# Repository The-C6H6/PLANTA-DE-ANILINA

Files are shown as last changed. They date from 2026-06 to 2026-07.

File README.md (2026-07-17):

# Diseño conceptual de una planta industrial de anilina

<div align="center">

**Hidrogenación catalítica de nitrobenceno · 33 000 t/año · Coatzacoalcos, Veracruz**

Proyecto técnico-académico de diseño de planta que integra simulación en Aspen HYSYS, balances de materia y energía, red de integración térmica, P&ID, especificación preliminar de equipos, estimación económica, layout SLP y visualización 3D interactiva.

[**Reporte técnico**](<REPORTE/ANILINA___EQUIPO 6.pdf>) · [**Recorrido 3D**](<3D/VISUALIZACIÓN/GRABACIÓN 3D.mp4>) · [**Modelo interactivo**](<3D/index.standalone.html>) · [**Caso de HYSYS**](<SIMULACIÓN/ANILINA_99.hsc>)

</div>

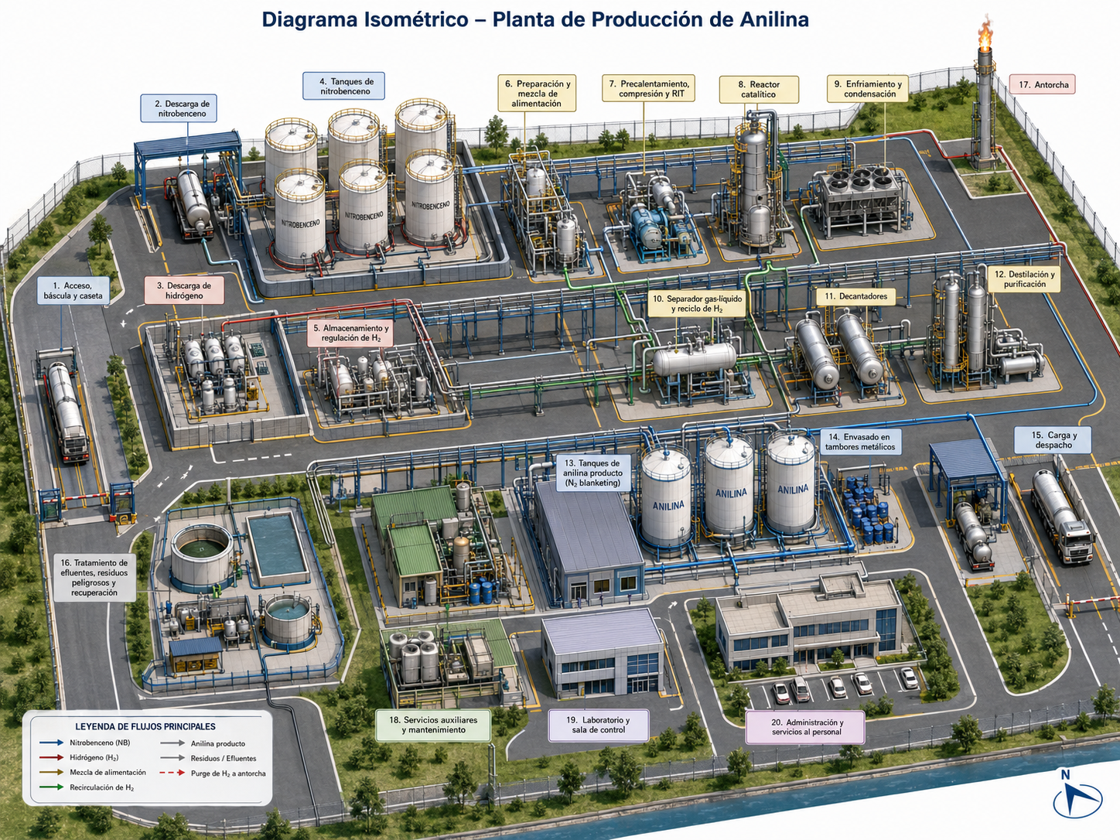
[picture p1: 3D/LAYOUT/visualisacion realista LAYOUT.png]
Vista isométrica de la planta de producción de anilina


> [!IMPORTANT]
> Este es un diseño conceptual con fines académicos. Los datos de proceso, seguridad y costos deben someterse a ingeniería básica y de detalle, HAZOP/LOPA, revisión normativa y validación independiente antes de cualquier uso industrial.

## Contenido

- [Visión general](#visión-general)
- [Fundamento químico](#fundamento-químico)
- [Proceso completo](#proceso-completo)
- [Diagramas de ingeniería y simulación](#diagramas-de-ingeniería-y-simulación)
- [Layout y diseño 3D](#layout-y-diseño-3d)
- [Equipos principales](#equipos-principales)
- [Seguridad y criterios de distribución](#seguridad-y-criterios-de-distribución)
- [Contenido del repositorio](#contenido-del-repositorio)
- [Cómo explorar el proyecto](#cómo-explorar-el-proyecto)
- [Alcance y limitaciones](#alcance-y-limitaciones)

## Visión general

La propuesta desarrolla una planta de operación continua para producir **anilina grado técnico** mediante la hidrogenación catalítica de nitrobenceno. El diseño considera recuperación de materias primas no reaccionadas, integración térmica, separación gas-líquido, decantación, purificación por destilación y manejo final del producto.

La localización conceptual es el entorno industrial del **Complejo Petroquímico Pajaritos, Coatzacoalcos, Veracruz, México**, seleccionado por su infraestructura petroquímica, acceso logístico y cercanía potencial a materias primas y servicios.

| Indicador | Valor de diseño o simulación |
| --- | ---: |
| Producto principal | Anilina grado técnico |
| Capacidad nominal | 33 000 t/año |
| Producción simulada | 32 268.45 t/año |
| Producción horaria | 3.841482 t/h |
| Régimen de operación | 350 días/año; 8 400 h/año |
| Conversión en el reactor | 96 % |
| Pureza molar del producto | 97.7 % |
| Presión aproximada de reacción | 5 bar |
| Temperatura de entrada al reactor | 340 °C |
| Inversión total preliminar | USD 4 070 400 |
| Materias primas | USD 57 161 700/año |
| Servicios auxiliares | USD 1 135 841.82/año |

Los valores económicos corresponden a la estimación académica del proyecto y no representan cotizaciones vigentes de mercado.

## Fundamento químico

La reacción principal es la reducción del grupo nitro del nitrobenceno con hidrógeno:

```text
C6H5NO2 + 3 H2  →  C6H5NH2 + 2 H2O
Nitrobenceno        Anilina       Agua
```

- **Materia prima orgánica:** nitrobenceno.
- **Agente reductor:** hidrógeno.
- **Catalizador considerado:** paladio soportado en alúmina.
- **Producto:** anilina.
- **Subproducto estequiométrico:** agua.
- **Naturaleza del sistema:** reacción exotérmica en fase gaseosa, con control térmico y recuperación de calor.

## Proceso completo

### 1. Alimentación y recuperación de materias primas

El nitrobenceno fresco se combina con el nitrobenceno recuperado en la sección de purificación. En paralelo, el hidrógeno fresco se mezcla con el hidrógeno recirculado desde el separador gas-líquido. Estos reciclos disminuyen pérdidas de reactivos y reducen la demanda de alimentación fresca.

### 2. Precalentamiento e integración térmica

La corriente total de hidrógeno se precalienta en **E-101** hasta aproximadamente 220 °C aprovechando energía del efluente caliente del reactor; después alcanza cerca de 310 °C con servicio de calentamiento. El nitrobenceno sigue un acondicionamiento equivalente mediante recuperación de calor y calentamiento final hasta aproximadamente 310 °C.

### 3. Mezcla, compresión y reacción

Las alimentaciones calientes se mezclan y se comprimen hasta cerca de 5 bar. Antes de ingresar al reactor catalítico **CRV-100**, la mezcla alcanza aproximadamente 340 °C. La conversión de nitrobenceno establecida en la simulación es de 96 %. Debido al carácter exotérmico de la reacción, el reactor requiere control de temperatura y una estrategia de remoción de calor.

### 4. Enfriamiento y recuperación de hidrógeno

El efluente del reactor, compuesto por anilina, agua, hidrógeno y nitrobenceno no reaccionados, entrega parte de su energía a las corrientes frías del proceso. Posteriormente se enfría hasta unos 30 °C y entra al separador **V-101**. La fase gaseosa rica en H₂ se divide entre una purga de seguridad hacia antorcha y una corriente de recirculación.

### 5. Decantación de la fase líquida

La fase líquida pasa al decantador **V-100**, donde se separa una fase acuosa de una fase orgánica rica en anilina y nitrobenceno. La separación líquido-líquido reduce la carga de agua que llegará a la destilación.

### 6. Primera etapa de destilación

La fase orgánica se acondiciona a unos 110 °C antes de entrar a **T-101**. Esta columna retira agua residual, compuestos ligeros e impurezas. Una segunda decantación en **V-102** recupera la fracción orgánica presente en la corriente superior.

### 7. Purificación final y reciclo de nitrobenceno

Las corrientes orgánicas recuperadas se combinan en **MIX-102** y alimentan la segunda columna, **T-100**. La columna opera al vacío, aproximadamente a 0.05 atm en el modelo, para efectuar la separación final anilina-nitrobenceno. La anilina sale como producto con una pureza aproximada de 97.7 % mol; el nitrobenceno de fondos regresa al inicio del proceso.

### 8. Almacenamiento, envasado y despacho

El producto purificado se dirige a tanques con blanketing de nitrógeno, seguido de envasado en tambores metálicos o carga a transporte. El layout incorpora laboratorio, sala de control, servicios auxiliares, mantenimiento y tratamiento de efluentes.

## Diagramas de ingeniería y simulación

### Diagrama de bloques

La vista de bloques resume la trayectoria principal y muestra los dos lazos de recuperación: **A** para nitrobenceno y **B** para hidrógeno.

Diagrama de bloques del proceso de anilina

[Abrir el diagrama de bloques original en PDF](<DIAGRAMAS/Bloques Anilina.pdf>)

### Diagrama de flujo sin integración térmica

Esta representación identifica los equipos principales y permite seguir el proceso base antes de incorporar los intercambios de energía entre corrientes.

Diagrama de flujo del proceso sin integración térmica

[Abrir el diagrama de flujo original en PDF](<DIAGRAMAS/Diagrama de flujo sin integración termica.pdf>)

### Red de Integración Térmica (RIT)

La RIT aprovecha el efluente caliente del reactor para precalentar corrientes de alimentación. En particular, **E-101** recupera calor para el hidrógeno y la red asociada a **E-106** reduce la carga térmica del acondicionamiento de nitrobenceno/mezcla reactiva. Los calentadores y enfriadores de servicio completan los niveles de temperatura requeridos.

Red de integración térmica de la planta de anilina

[Abrir el archivo editable de la RIT](DIAGRAMAS/RIT.eddx)

### Simulación en Aspen HYSYS

El flowsheet integra alimentaciones frescas, reciclos, reactor de conversión, separadores, decantadores, columnas y corrientes de energía. Los archivos de simulación permiten consultar propiedades, composiciones y resultados del caso.

Flowsheet de simulación en Aspen HYSYS

[Abrir el caso de Aspen HYSYS](<SIMULACIÓN/ANILINA_99.hsc>) · [Consultar tablas de corrientes](TUBERIAS)

### Diagramas de tuberías e instrumentación (P&ID)

El repositorio incluye entregables en PDF y DWG para los principales nodos del proceso:

| Subsistema | Documentos destacados |
| --- | --- |
| Almacenamiento y protección | [Tanque de nitrobenceno](<PID/PDF/TANQUE DE NITROBENCENO.pdf>) · [Tanque de hidrógeno](<PID/PDF/TANQUE DE HIDROGENO.pdf>) · [Blanketing](PID/PDF/BLANKETING.pdf) |
| Alimentación y reacción | [Compresor](PID/PDF/COMPRESOR.pdf) · [Mezclador MIX-102](<PID/PDF/MIXER 102.pdf>) · [Reactor enchaquetado](<PID/PDF/REACTOR ENCHAQUETADO.pdf>) |
| Enfriamiento y separación | [Separador V-101](PID/PDF/SEPARADOR001.pdf) · [Decantador V-100](<PID/PDF/DECANTADOR V100.pdf>) · [Decantador V-102](<PID/PDF/DECANTADOR V102.pdf>) |
| Purificación | [Columna T-100](<PID/PDF/Columna de destilacion T_100.pdf>) · [Columna T-101](<PID/PDF/Columna de destilacion T_101.pdf>) |
| Recuperación térmica | [Intercambiador de H₂](<PID/PDF/INTERCAMBIADOR DE H2.pdf>) · [Intercambiador de mezcla](<PID/PDF/INTERCAMBIADOR DE MEZCLA.pdf>) · [E-105](<PID/PDF/INTERCAMBIADOR DESPUES NITROBENCENO.pdf>) |
| Seguridad | [Antorcha](PID/PDF/TORCH.pdf) |

[Explorar todos los P&ID en PDF](PID/PDF) · [Explorar los archivos DWG](PID/DWG)

## Layout y diseño 3D

### Distribución conceptual por bloques

El layout se desarrolló con un enfoque **SLP (Systematic Layout Planning)**. La secuencia física sigue el flujo recepción → almacenamiento → reacción → separación → purificación → producto → despacho, mientras las áreas de mayor riesgo se mantienen segregadas.

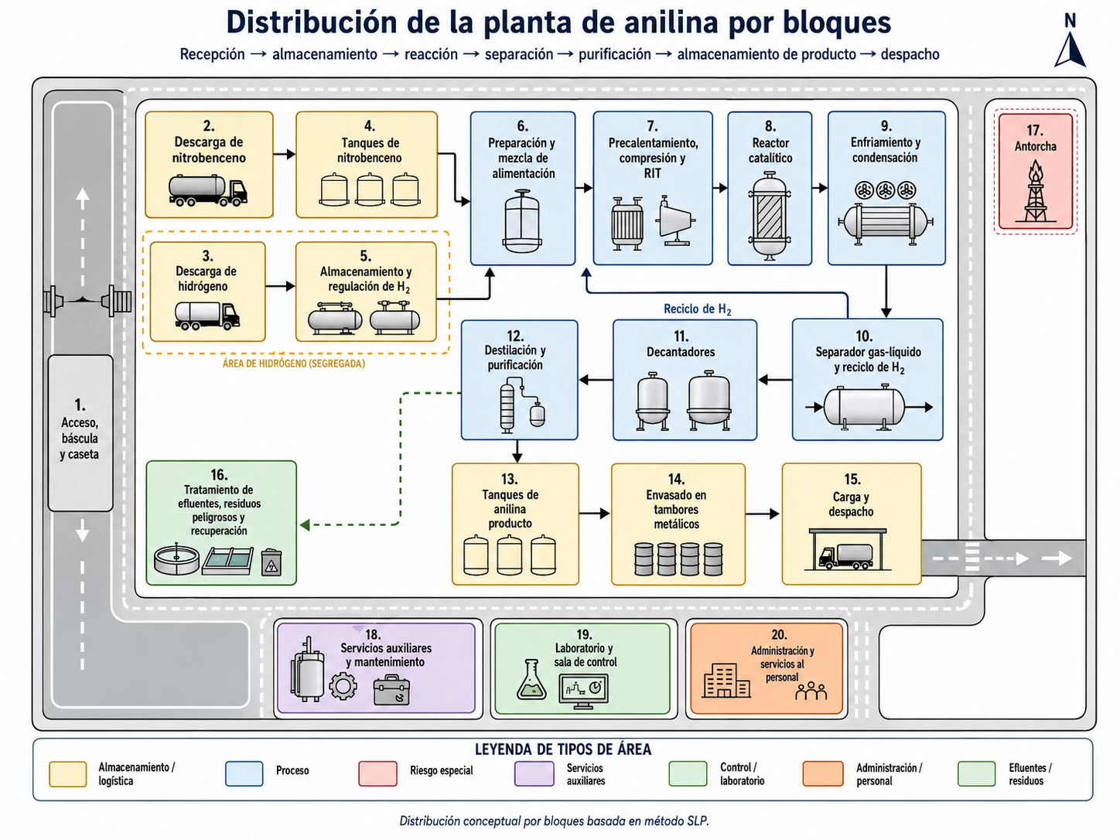
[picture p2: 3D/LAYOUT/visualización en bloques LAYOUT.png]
Distribución de la planta de anilina por bloques


| Zonas | Función dentro del layout |
| --- | --- |
| 1-5 | Acceso, báscula, descarga y almacenamiento de nitrobenceno e hidrógeno |
| 6-12 | Preparación de alimentación, compresión, reacción, enfriamiento, separación y purificación |
| 13-15 | Almacenamiento de anilina, envasado, carga y despacho |
| 16-17 | Tratamiento de efluentes y antorcha |
| 18-20 | Servicios, mantenimiento, laboratorio, sala de control y administración |

### Vista isométrica realista

La representación isométrica convierte los bloques funcionales en una propuesta espacial con vialidades, racks de tuberías, diques de contención, áreas de carga, servicios, edificios y equipos principales.

Layout isométrico realista de la planta

### Recorrido en video

La imagen siguiente funciona como portada del recorrido. Selecciónala para abrir el archivo MP4 del modelo 3D.

Reproducir recorrido 3D de la planta de anilina

▶ **[Reproducir o descargar la grabación 3D](<3D/VISUALIZACIÓN/GRABACIÓN 3D.mp4>)**

### Modelo Three.js interactivo

El archivo autónomo [3D/index.standalone.html](<3D/index.standalone.html>) contiene el modelo y la biblioteca necesaria en una sola página. Permite:

- orbitar, acercar y alejar la cámara;
- enfocar materias primas, reacción, separación, producto y servicios;
- activar o desactivar etiquetas y tuberías;
- usar giro automático;
- recorrer la planta en modo juego con `WASD`, ratón y `Shift`.

Para ejecutarlo, descarga el repositorio y abre el archivo HTML en un navegador moderno; no requiere instalación ni servidor local.

## Equipos principales

| Sección | Equipos o etiquetas representativas | Función |
| --- | --- | --- |
| Alimentación | T-01/T-02, MIX-103, MIX-101 | Almacenamiento, combinación de corrientes frescas y reciclos |
| Acondicionamiento | E-100, H-100, E-101, E-106 | Precalentamiento con servicios e integración térmica |
| Compresión | CO-100 | Elevar la presión de la mezcla reactiva |
| Reacción | CRV-100 | Conversión catalítica de nitrobenceno a anilina |
| Enfriamiento | E-101, E-103 | Recuperación de calor y condensación del efluente |
| Separación primaria | V-101 | Separación de H₂ y fase líquida; reciclo y purga |
| Decantación | V-100, V-102 | Separación de agua y recuperación de fase orgánica |
| Purificación | T-101, T-100, MIX-102 | Remoción de ligeros/agua y separación final al vacío |
| Seguridad y almacenamiento | Antorcha, tanques de producto, blanketing de N₂ | Manejo de purgas y conservación segura del producto |

Las hojas preliminares disponibles incluyen el análisis hidráulico de **T-101**, la especificación de la columna y archivos de diseño del intercambiador **E-105**. Véase [ESPECIFICACIÓNES DE EQUIPOS](<ESPECIFICACIÓNES DE EQUIPOS>).

## Seguridad y criterios de distribución

- **Hidrógeno:** almacenamiento segregado, control de fuentes de ignición, venteos y purgas dirigidos a un sistema seguro.
- **Nitrobenceno y anilina:** manejo en sistemas cerrados, contención secundaria, ventilación, detección de fugas y tratamiento de derrames/efluentes.
- **Reacción exotérmica:** control independiente de temperatura y presión, alarmas, interbloqueos, alivio y aislamiento de emergencia.
- **Antorcha:** ubicación periférica para recibir la purga de hidrógeno y otras descargas previstas por el diseño.
- **Tránsito y emergencia:** vialidad perimetral, accesos diferenciados, zonas de carga separadas y espacio para atención de emergencias.
- **Operación:** sala de control y laboratorio fuera del núcleo de proceso, con servicios y mantenimiento próximos pero físicamente diferenciados.

Estas medidas son criterios conceptuales; la selección final de distancias, protecciones, instrumentación y sistemas contra incendio requiere estudios formales de riesgo y cumplimiento de la normativa aplicable.

## Contenido del repositorio

| Recurso | Ubicación | Contenido |
| --- | --- | --- |
| Reporte completo | [REPORTE](REPORTE) | Documento técnico de 126 páginas en PDF |
| Documento editable | [WORD](WORD) | Versión DOCX del reporte |
| Simulación | [SIMULACIÓN](<SIMULACIÓN>) | Caso y respaldo de Aspen HYSYS |
| Diagramas de proceso | [DIAGRAMAS](DIAGRAMAS) | Bloques, flujo sin integración térmica y RIT |
| P&ID | [PID/PDF](PID/PDF) y [PID/DWG](PID/DWG) | Diagramas por equipo en formatos de consulta y edición |
| Diseño 3D | [3D](3D) | Modelo Three.js, layouts, memoria y grabación MP4 |
| Equipos | [ESPECIFICACIÓNES DE EQUIPOS](<ESPECIFICACIÓNES DE EQUIPOS>) | Hojas y análisis de equipos seleccionados |
| Tuberías y corrientes | [TUBERIAS](TUBERIAS) | Propiedades, composiciones, energía, diámetros y resumen |
| Costos de equipos | [COSTOS DE EQUIPOS](<COSTOS DE EQUIPOS>) | Estimación en Excel por equipo |
| Costos totales | [COSTOS TOTALES](<COSTOS TOTALES>) | Inversión y costo anual del proceso |
| Servicios auxiliares | [SERVICIOS DE LA PLANTA](<SERVICIOS DE LA PLANTA>) | Consumos y costos de servicios |

## Cómo explorar el proyecto

1. Comienza con el [reporte técnico completo](<REPORTE/ANILINA___EQUIPO 6.pdf>) para revisar bases, balances, localización, costos y referencias.
2. Revisa el [diagrama de bloques](<DIAGRAMAS/Bloques Anilina.pdf>) y la [RIT](DIAGRAMAS/RIT.jpg) para entender la lógica del proceso.
3. Abre [3D/index.standalone.html](<3D/index.standalone.html>) localmente para recorrer la distribución de planta.
4. Reproduce la [grabación 3D](<3D/VISUALIZACIÓN/GRABACIÓN 3D.mp4>) si deseas una visita guiada sin interactuar con el modelo.
5. Usa [SIMULACIÓN/ANILINA_99.hsc](<SIMULACIÓN/ANILINA_99.hsc>) en una instalación compatible de Aspen HYSYS para consultar o recalcular el caso.
6. Profundiza en los [P&ID](PID/PDF), las [tablas de tuberías](TUBERIAS) y los [libros de costos](<COSTOS TOTALES>).

## Alcance y limitaciones

El proyecto cubre selección de ruta, localización conceptual, descripción del proceso, simulación, diagramas, equipos principales, tuberías, servicios, costos, layout y representación 3D. No sustituye:

- ingeniería básica o de detalle certificada;
- validación experimental de cinética y catalizador;
- diseño mecánico completo y cálculo estructural;
- análisis dinámico, SIL, HAZOP, LOPA o QRA;
- permisos ambientales, uso de suelo o cumplimiento regulatorio;
- cotizaciones comerciales y evaluación financiera con precios actualizados.

## Contexto académico

| Campo | Información |
| --- | --- |
| Institución | Instituto Politécnico Nacional |
| Escuela | Escuela Superior de Ingeniería Química e Industrias Extractivas |
| Materia | Diseño de Plantas Industriales |
| Grupo | 5IM93 |
| Profesor | Gasca Reyes Luis Germán |
| Fecha de entrega | 27 de junio de 2026 |

### Integrantes

- Vázquez Pérez Diego
- Hernández González Mónica
- Esquivel Arriaga Isaac

---

Si este repositorio te resulta útil, consulta el reporte para conocer las bases de cálculo, supuestos y referencias que respaldan cada sección del diseño.

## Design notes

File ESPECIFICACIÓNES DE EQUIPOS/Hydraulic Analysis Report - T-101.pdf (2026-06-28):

# Hydraulic Analysis Report - T-101 : Internals-1@Main Tower@COL1

## Generated by Aspen HYSYS V14

## Simulation case: C:\Users\C6H6_\Downloads\ANILINA_99.hsc

23/06/2026

# Contents

1. Column Internals Summary--------------------------------------------------------------------------------------------------------------- 3
2. Feed/Draw Summary----------------------------------------------------------------------------------------------------------------------- 4
3. CS-1---------------------------------------------------------------------------------------------------------------------------------------------5
3.1. Tray Geometry----------------------------------------------------------------------------------------------------------------------------- 5
3.2. Design Parameters------------------------------------------------------------------------------------------------------------------------7

## Hydraulic Analysis Report - T-101 : Internals-1@Main Tower@COL1

User Name: | ESIQIE | Job Code:
Project: | T-101 | Description: | TORRE DE DESTILACION T-101
1. Column Internals Summary
| | Summary
Property | Value | Units
Number of Trayed/Packed stages | 6
Total height | 3.658 | m
Total head loss (Hot liquid height) | 437.5 | mm
Total pressure drop | 40.89 | mbar
Number of sections | 1
Number of diameters | 1
Total residence time | 8.488 | seconds

Sections
Section | Start | End | Diameter (m) | Section Height (m) | Internals Type | Tray or Packing Type | Section Pressure Drop (mbar) | % Approach to Flood | Limiting Stage
CS-1 | 1_Main Tower | 6_Main Tower | 0.5044 | 3.658 | Trayed | Sieve | 40.89 | 80.0003 | 6_Mai n Tower
Page 3 of 7 | 23/06/2026

User Name: | ESIQIE | Job Code:
Project: | T-101 | Description: | TORRE DE DESTILACION T-101
2. Feed/Draw Summary
| | Feed/Draw Summary
Stage Number | Stream | Feed/Draw
1_Main Tower | Reflux | Feed
| ORG-110 | Feed
| To Condenser | Draw
6_Main Tower | Boilup | Feed
| To Reboiler | Draw
Page 4 of 7 | 23/06/2026

User Name: | ESIQIE | Job Code:
Project: | T-101 | Description: | TORRE DE DESTILACION T-101
3. CS-1
3.1. Tray Geometry
| | Section
Property | Value | Units
Tray type | SIEVE
Diameter | 0.5044 | m
Tray spacing | 0.6096 | m
Number of passes | 1
Hole diameter | 0.0127 | m
Hole area / Active area | 0.1
Number of Holes | 126
Deck gauge thickness | 10 GAUGE
Deck gauge thickness value | 3.404 | mm
Cross-sectional area | 0.1998 | m2
Active area | 0.1598 | m2
Net area | 0.1798 | m2

Downcomer geometry

Property | Side | Units
Downcomer clearance | 0.0381 | m
Downcomer width top | 0.07892 | m
Downcomer width bottom | 0.07892 | m
Downcomer area top | 0.01998 | m2
Downcomer area bottom | 0.01998 | m2

Weir geometry

Property | Side | Units
Weir height | 0.0508 | m
Page 5 of 7 | 23/06/2026

User Name: | ESIQIE | Job Code:
Project: | T-101 | Description: | TORRE DE DESTILACION T-101
Property | Side | Units
Weir length | 0.3665 | m

Panels

Property | A | Units
Flow path length | 0.3465 | m
Bubbling area | 0.1598 | m2
Page 6 of 7 | 23/06/2026

User Name: | ESIQIE | Job Code:
Project: | T-101 | Description: | TORRE DE DESTILACION T-101
3.2. Design Parameters
Design Parameters
Property | Value | Units
% Jet flood and downcomer choke flood for design | 80
Minimum downcomer area / Total tray area | 0.1

Downcomer design basis

Maximum acceptable pressure drop | 2.5 | kPa
Maximum % jet flood | 100
Maximum % downcomer backup | 100
Maximum % liquid entrainment | 10
Minimum weir loading | 4.471 | m3/h-m
Maximum weir loading | 117.4 | m3/h-m
Warning status (% to limit) | 10
System foaming factor | 1
Aeration factor multiplier | 1
Over design factor | 1
Overall section efficiency | 1
Weep method | Hsieh
Jet flood method | Glitsch6
Maximum downcomer loading method | Glitsch
Dry pressure drop multiplier | 1
Page 7 of 7 | 23/06/2026

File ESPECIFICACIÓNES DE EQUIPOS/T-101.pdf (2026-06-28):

Company Name Not Available Bedford, MA
USA
Case Name: | ANILINA_99.hsc
Unit Set: | SI10a1
Date/Time: | Wed Jun 24 18:48:37 2026

# Distillation: T-101 @Main

### CONNECTIONS

11 | Inlet Stream
12 | Stream Name | Stage | From Unit Operation
13 | R-T101 | Reboiler
14 | ORG-110 | 1__Main Tower | Heater E-104
15 | Outlet Stream
16 | Stream Name | Stage | To Unit Operation
17 | C-T101 | Condenser
18 | H2O | Condenser | 3 Phase Separator V-102
19 | ORG-SEP | Reboiler | Cooler E-105
20 | H2 | Condenser
21 | MONITOR
23 | Specifications Summary
24 | | Specified Value | Current Value | Wt. Error
25 | Reflux Ratio | 2.000 * | 2.000 | -2.839e-008
26 | Distillate Rate | --- | 14.36 kgmole/h | ---
27 | Reflux Rate | 30.16 kgmole/h * | 28.85 kgmole/h | -4.341e-002
28 | Btms Prod Rate | --- | 41.62 kgmole/h | ---
29 | Vent Rate | 7.000e-002 kgmole/h * | 7.000e-002 kgmole/h | 3.773e-006
30 | REC H2O | 0.9900 * | 0.9900 | 9.044e-008
31 | | Wt. Tol. | Abs. Tol. | Active | Estimate | Used
32 | Reflux Ratio | 1.000e-002 | 1.000e-002 | On | On | On
33 | Distillate Rate | 1.000e-002 | 1.000 kgmole/h | Off | Off | Off
34 | Reflux Rate | 1.000e-002 | 1.000 kgmole/h | Off | On | Off
35 | Btms Prod Rate | 1.000e-002 | 1.000 kgmole/h | Off | On | Off
36 | Vent Rate | 1.000e-002 | 1.000 kgmole/h | On | On | On
37 | REC H2O | 1.000e-002 | 1.000e-003 | On | On | On
38 | SPECS
40 | Column Specification Parameters
41 | Reflux Ratio
43 | Fix/Rang: Fixed | Prim/Alter: Primary | Lower Bnd: --- | Upper Bnd: ---
44 | Stage: Condenser | Flow Basis: Molar | Liquid Spec: ---
45 | Distillate Rate
47 | Fix/Rang: Fixed | Prim/Alter: Primary | Lower Bnd: --- | Upper Bnd: ---
48 | Stream: H2O | Flow Basis: Molar
49 | Reflux Rate
51 | Fix/Rang: Fixed | Prim/Alter: Primary | Lower Bnd: --- | Upper Bnd: ---
52 | Stage: Condenser | Flow Basis: Molar | Liquid Spec: ---
53 | Btms Prod Rate
55 | Fix/Rang: Fixed | Prim/Alter: Primary | Lower Bnd: --- | Upper Bnd: ---
56 | Stream: ORG-SEP | Flow Basis: Molar
57 | Vent Rate
59 | Fix/Rang: Fixed | Prim/Alter: Primary | Lower Bnd: --- | Upper Bnd: ---
60 | Stream: H2 | Flow Basis: Molar
61
Aspen Technology Inc. | Aspen HYSYS Version 14 | Page 1 of 11

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
Licensed to: Company Name Not Available | * Specified by user.

| Bedford, MA USA
6 | Distillation: T-101 @Main (continued)
Unit Set: | SI10a1
Date/Time: | Wed Jun 24 18:48:37 2026
9 | Column Specification Parameters
10 | REC H2O
12 | Fix/Rang: Fixed | Prim/Alter: Primary | Lower Bnd: --- | Upper Bnd: ---
13 | Draw: H2O | Flow Basis: Molar
14 | Components: | H2O
15 | SUBCOOLING
17 | | Condenser
18 | Degrees of Subcooling | ---
19 | Subcool to | ---
20 | User Variables

### ACTIVE INTERNAL OPTION: Internals-1@Main Tower@COL1

24 | Name | Start Stage | End Stage | Mode | Internals | Tray / Packing Type
25 | CS-1 | 1__Main Tower | 6__Main Tower | Interactive Sizing | Trayed | Sieve
26 | Number of Passes | Packing Vendor | Packing Material | Packing Dimension | Tray Spacing / Section Packed Height (m) | Diameter (m)
28 | 1 | --- | --- | --- | 0.6096 | 0.5044
29 | SETUP
31 | Section Name | CS-1
32 | Section Start | 1__Main Tower
33 | Section End | 6__Main Tower
34 | Internals | Trayed
35 | Internals Type | Sieve
36 | Diameter (m) | 0.5044
37 | Tray Spacing / Section Packed Height (m) | 0.6096
38 | Number Of Passes | 1
39 | Maximum Acceptable Pressure Drop (kPa) | 2.500
40 | Maximum Percent Downcomer Backup | 100.00 %
41 | Maximum Percent Jet Flood | 100.00 %
42 | Percent Jet Flood For Design | 80.00 %
43 | Maximum Percent Liquid Entrainment | 10.00 %
44 | Minimum Weir Loading (m3/h-m) | 4.471
45 | Maximum Weir Loading (m3/h-m) | 117.4
46 | Minimum Downcomer Area / Total Tray Area | 0.1000
47 | Override Downcomer Froth Density | No
48 | Froth Density | ---
49 | Weep Method | Hsieh
50 | Default Jet Flood Calculation Method | GLITSCH6
51 | Maximum Downcomer Loading Method | Glitsch
52 | % Approach to Maximum Capacity | ---
53 | Design Capacity Factor | ---
54 | Capacity Factor at Flooding | ---
55 | System Foaming Factor | 1.000
56 | Aeration Factor Multipler | 1.000
57 | Minimum Liquid Flow Rate | ---
58 | Pressure Drop at Flood per Unit Packed Height | ---
59 | Allowable Pressure Drop per Unit Packed Height | ---
60 | Minimum Pressure Drop per Unit Packed Height | ---
| Number of Curves | ---
| Warning Status (% to Limit) | 10.00 % *
| Aspen Technology Inc. Aspen HYSYS Version 14 Page 2 of 11

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
| Bedford, MA USA
6 | Distillation: T-101 @Main (continued)
Unit Set: | SI10a1
Date/Time: | Wed Jun 24 18:48:37 2026

### ACTIVE INTERNAL OPTION: Internals-1@Main Tower@COL1

### SETUP

13 | Pressure Drop Calculation Method | ---
14 | Mode | Interactive Sizing
15 | Status | Needs Calculating
16 | GEOMETRY DETAILS
18 | Common Geometry | CS-1
19 | Section Start | 1__Main Tower
20 | Section End | 6__Main Tower
21 | Internals | Sieve
22 | Section Diameter (m) | 0.5044
23 | Foaming Factor | 1.000
24 | Over-Design Factor | 1.000
25 | Common Tray Geometry | CS-1
26 | Number of Passes | 1
27 | Tray Spacing (m) | 0.6096
28 | Picket Fence Weirs | No
29 | Swept Back Weirs | No
30 | Active Area Under Downcomer | No
31 | Deck Thickness | 10 Gauge
32 | Deck Thickness Value (mm) | 3.404
33 | Balance Downcomers Based On
34 | Weir Modifications | None
35 | Net Area (m2) | 0.1798
36 | Cross-Sectional Area (m2) | 0.1998
37 | Active Area (m2) | 0.1598
38 | Downcomer Geometry | CS-1
39 | Side | Weir Height (mm) | 50.80 *
40 | | Weir Length (m) | ---
41 | | Downcomer Clearance (mm) | 38.10
42 | | Downcomer Width - Top (mm) | 78.92
43 | | Downcomer Width - Bottom (mm) | 78.92
44 | | Downcomer Loading Top (m3/h-m2) | 238.3 *
45 | | Weir Loading (m3/h-m) | 19.76
46 | | Downcomer Area - Top (m2) | 1.998e-002
47 | | Downcomer Area - Bottom (m2) | 1.998e-002
48 | | Picketing Fraction | ---
49 | Center | Weir Height (mm) | ---
50 | | Weir Length (m) | ---
51 | | Downcomer Clearance (mm) | ---
52 | | Downcomer Width - Top (mm) | ---
53 | | Downcomer Width - Bottom (mm) | ---
54 | | Downcomer Loading Top (m3/h-m2) | ---
55 | | Weir Loading (m3/h-m) | ---
56 | | Downcomer Area - Top (m2) | ---
57 | | Downcomer Area - Bottom (m2) | ---
58 | | Picketing Fraction | ---
59 | Off Center | Weir Height (mm) | ---
60 | | Inside Weir Length (m) | ---
| | Outside Weir Length (m) | ---
| | Downcomer Clearance (mm) | ---
| Aspen Technology Inc. Aspen HYSYS Version 14 Page 3 of 11

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
| Bedford, MA USA
6 | Distillation: T-101 @Main (continued)
Unit Set: | SI10a1
Date/Time: | Wed Jun 24 18:48:37 2026

### ACTIVE INTERNAL OPTION: Internals-1@Main Tower@COL1

### GEOMETRY DETAILS

13 | Off Center | Downcomer Width - Top (mm) | ---
14 | | Downcomer Width - Bottom (mm) | ---
15 | | Downcomer Loading Top (m3/h-m2) | ---
16 | | Maximum Outside Weir Loading(m3/h-m) | ---
17 | | Maximum Inside Weir Loading (m3/h-m) | ---
18 | | Downcomer Area - Top (m2) | ---
19 | | Downcomer Area - Bottom (m2) | ---
20 | | Inside Picketing Fraction | ---
21 | | Outside Picketing Fraction | ---
22 | | Off-Center Downcomer Location (m) | ---
23 | Swept Back Weir Geometry | | CS-1
24 | Compatibility | | KG Tower
25 | A | | ---
26 | B/Parallel Chord Segment | | ---
27 | S/Swept-Back Weir | | ---
28 | Swept-Back Weir Chord | | ---
29 | Angled Chord Segment | | ---
30 | Tray With Maximum Weir Loading | | 6
31 | Maximum Weir Loading (m3/h-m) | | 19.76 *
32 | Maximum Allowable Weir Loading in Section(m3/h-m) | | 117.4 *
33 | Actual Side Weir Length (m) | | 0.3665
34 | Effective Side Weir Length (m) | | 0.3665
35 | Lost Area (%) | | 0.00
36 | Sieve Geometry | | CS-1
37 | Hole Diameter (mm) | | 12.70
38 | Number of Holes | | 126
39 | Hole Area to Active Area | | 0.1000
40 | Lattice Geometry | | CS-1
41 | Number Of Downcomers | | ---
42 | Downcomer End Gap (mm) | | ---
43 | Downcomer Width (mm) | | ---
44 | Downcomer Height (m) | | ---
45 | Downcomer Spacing (m) | | ---
46 | Liq Exit Area / Bottom Downcomer Area | | ---
47 | Weir Height (mm) | | ---
48 | Bubble Cap Geometry | | CS-1
49 | Cap Diameter | | ---
50 | Skirt Height | | ---
51 | Number of Caps | | ---
52 | Number of Caps Per Active Area | | ---
53 | Valve Geometry | | CS-1
54 | Tray Type | | ---
55 | Valve Type | | ---
56 | Valve Material | | ---
57 | Leg Length | | ---
58 | Valve Thickness | | ---
59 | Number of Valves | | ---
60 | Number of Valves per Active Area | | ---
Aspen Technology Inc. | Aspen HYSYS Version 14 | Page 4 of 11

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

### ACTIVE INTERNAL OPTION: Internals-1@Main Tower@COL1

### RESULTS SUMMARY

13 | Section Name | CS-1
14 | Section Start | 1__Main Tower
15 | Section End | 6__Main Tower
16 | Internals | Trayed
17 | Diameter (m) | 0.5044
18 | Number of Passes | 1
19 | Tray Spacing / Section Packed Height (m) | 0.6096
20 | Total Height (m) | 3.658
21 | Total Pressure Drop (mbar) | 40.89
22 | Total Pressure Drop (Head Loss) (mm) | 437.5
23 | Trays With Weeping | None
24 | Maximum Percent Jet Flood (%) | 80.00 *
25 | Tray With Maximum Jet Flood | 6__Main Tower
26 | Maximum Percent Downcomer Backup (%) | 37.38 *
27 | Tray With Maximum Downcomer Backup | 6__Main Tower
28 | Maximum Downcomer Loading (m3/h-m2) | 362.4 *
29 | Tray With Maximum Downcomer Loading | 6__Main Tower
30 | Maximum Downcomer Loading Location | Side
31 | Maximum Weir Loading (m3/h-m) | 19.76 *
32 | Tray With Maximum Weir Loading | 6__Main Tower
33 | Maximum Weir Loading Location | Side
34 | Maximum Aerated Height Over Weir (mm) | 104.1 *
35 | Tray With Maximum Aerated Height Over Weir | 6__Main Tower
36 | Maximum % Approach To System Limit (%) | 50.90 *
37 | Tray With Maximum % Approach To System Limit | 6__Main Tower
38 | Maximum Cs Based On Bubbling Area (m/s) | 0.1051 *
39 | Tray With Maximum Cs Based On Bubbling Area | 6__Main Tower
40 | Maximum % Capacity (Constant L/V) | 80.00
41 | Maximum Capacity Factor (m/s) | ---
42 | Section Pressure Drop (mbar) | 40.89
43 | Average Pressure Drop Per Height (mbar/m) | ---
44 | Average Pressure Drop Per Height (Frictional) (mbar/m) | ---
45 | Maximum Stage Liquid Holdup (m3) | ---
46 | Maximum Liquid Superficial Velocity (m3/h-m2) | ---
47 | Surface Area (m2/m3) | ---
48 | Void Fraction | ---
49 | 1st Stichlmair Constant | ---
50 | 2nd Stichlmair Constant | ---
51 | 3rd Stichlmair Constant | ---
52 | STAGE BY STAGE RESULTS: CS-1
54 | State Conditions
55 | Stages | Liquid Temperature (C) | Vapor Temperature (C) | Liquid Mass Flow (kg/h) | Vapor Mass Flow (kg/h) | Liquid Volume Flow (m3/s) | Vapor Volume Flow (m3/s)
57 | 1__Main Tower | 94.65 | 99.09 | 4592 | 860.9 | 1.323e-003 | 0.3389
58 | 2__Main Tower | 94.66 | 94.66 | 4592 | 673.9 | 1.323e-003 | 0.2702
59 | 3__Main Tower | 94.66 | 94.69 | 4592 | 674.1 | 1.323e-003 | 0.2702
60 | 4__Main Tower | 94.69 | 96.62 | 4601 | 683.0 | 1.325e-003 | 0.2711
| 5__Main Tower | 96.62 | 134.2 | 4961 | 1042 | 1.433e-003 | 0.2810
| 6__Main Tower | 134.2 | 179.3 | 6718 | 2800 | 2.011e-003 | 0.3360
| Aspen Technology Inc. Aspen HYSYS Version 14 Page 5 of 11

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

### ACTIVE INTERNAL OPTION: Internals-1@Main Tower@COL1

### STAGE BY STAGE RESULTS: CS-1

13 | Physical Conditions
14 | Stages | Liquid Molecular Weight | Vapor Molecular Weight | Liquid Mass Density (kg/m3) | Vapor Mass Density (kg/m3) | Liquid Viscosity (cP) | Vapor Viscosity (cP) | Surface Tension (dyne/cm)
16 | 1__Main Tower | 62.19 | 21.55 | 964.4 | 0.7056 | 0.8286 | 9.382e-003 | 45.87
17 | 2__Main Tower | 62.19 | 20.91 | 964.4 | 0.6929 | 0.8286 | 9.222e-003 | 45.87
18 | 3__Main Tower | 62.19 | 20.92 | 964.4 | 0.6929 | 0.8286 | 9.223e-003 | 45.87
19 | 4__Main Tower | 62.36 | 21.23 | 964.3 | 0.6998 | 0.8292 | 9.293e-003 | 45.80
20 | 5__Main Tower | 69.02 | 34.45 | 961.5 | 1.031 | 0.8429 | 1.058e-002 | 43.41
21 | 6__Main Tower | 90.55 | 85.95 | 927.8 | 2.315 | 0.5605 | 9.369e-003 | 31.92
22 | Hydraulic Results
23 | Stages | Percent Jet Flood (%) | Dry Pressure Drop (mbar) | Total Pressure Drop (mbar) | Dry Pressure Drop (Head Loss) (mm) | Total Pressure Drop (Head Loss) (mm)
25 | 1__Main Tower | 51.44 | 2.925 | 6.225 | 30.93 | 65.82
26 | 2__Main Tower | 41.45 | 1.826 | 5.549 | 19.30 | 58.67
27 | 3__Main Tower | 41.45 | 1.826 | 5.549 | 19.31 | 58.67
28 | 4__Main Tower | 41.71 | 1.856 | 5.565 | 19.63 | 58.85
29 | 5__Main Tower | 48.71 | 2.936 | 6.266 | 31.14 | 66.45
30 | 6__Main Tower | 80.00 | 9.430 | 11.74 | 103.6 | 129.0
31 | Stages | Downcomer Backup (Aerated) (m) | Downcomer Backup (Unaerated) (m) | Percent Downcomer Backup (Aerated) (%) | Percent Downcomer Backup (Unaerated) (%)
33 | 1__Main Tower | 0.1571 | 9.553e-002 | 23.78 | 14.47
34 | 2__Main Tower | 0.1527 | 9.286e-002 | 23.12 | 14.06
35 | 3__Main Tower | 0.1527 | 9.286e-002 | 23.12 | 14.06
36 | 4__Main Tower | 0.1527 | 9.291e-002 | 23.13 | 14.07
37 | 5__Main Tower | 0.1588 | 9.662e-002 | 24.05 | 14.63
38 | 6__Main Tower | 0.2469 | 0.1501 | 37.38 | 22.73
39 | Stages | Mass Rate / Column Area (kg/s-m2) | Volume Rate / Column Area (m3/h-m2) | Fs (Net Area) (sqrt(Pa)) | Fs (Bubble Area) (sqrt(Pa)) | Cs (Net Area) (m/s)
41 | 1__Main Tower | 6.384 | 23.83 | 1.583 | 1.781 | 5.100e-002
42 | 2__Main Tower | 6.384 | 23.83 | 1.251 | 1.407 | 4.029e-002
43 | 3__Main Tower | 6.384 | 23.83 | 1.251 | 1.407 | 4.029e-002
44 | 4__Main Tower | 6.397 | 23.88 | 1.261 | 1.419 | 4.063e-002
45 | 5__Main Tower | 6.897 | 25.82 | 1.586 | 1.784 | 5.118e-002
46 | 6__Main Tower | 9.340 | 36.24 | 2.843 | 3.198 | 9.344e-002
47 | Stages | Cs (Bubble Area) (m/s) | Approach to System Limit (%) | Height Over Weir (Aerated) (m) | Height Over Weir (Unaerated) (m)
49 | 1__Main Tower | 5.737e-002 | 25.14 | 6.436e-002 | 1.466e-002
50 | 2__Main Tower | 4.532e-002 | 19.85 | 5.747e-002 | 1.551e-002
51 | 3__Main Tower | 4.533e-002 | 19.86 | 5.748e-002 | 1.551e-002
52 | 4__Main Tower | 4.571e-002 | 20.03 | 5.779e-002 | 1.550e-002
53 | 5__Main Tower | 5.758e-002 | 25.67 | 6.796e-002 | 1.546e-002
54 | 6__Main Tower | 0.1051 | 50.90 | 0.1041 | 1.753e-002
55 | Side Downcomer Results
56 | Stages | Volume (m3) | Residence Time (seconds) | Velocity From Top (m/s) | Velocity from Bottom (m/s) | Exit Velocity (m/s)
58 | 1__Main Tower | 1.909e-003 | 1.443 | 6.620e-002 | 6.620e-002 | 9.473e-002
59 | 2__Main Tower | 1.855e-003 | 1.403 | 6.620e-002 | 6.620e-002 | 9.473e-002
60 | 3__Main Tower | 1.855e-003 | 1.403 | 6.620e-002 | 6.620e-002 | 9.473e-002
| 4__Main Tower | 1.856e-003 | 1.400 | 6.634e-002 | 6.634e-002 | 9.493e-002
| 5__Main Tower | 1.930e-003 | 1.347 | 7.173e-002 | 7.173e-002 | 0.1026
| Aspen Technology Inc. Aspen HYSYS Version 14 Page 6 of 11

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

### ACTIVE INTERNAL OPTION: Internals-1@Main Tower@COL1

### STAGE BY STAGE RESULTS: CS-1

Stages

15 | 6__Main Tower | 3.000e-003 | 1.491 | 0.1007 | 0.1007 | 0.1440
16 | RATING

Volume
(m3)

Residence Time
(seconds)

Velocity From Top
(m/s)

Velocity from Bottom
(m/s)

Exit Velocity
(m/s)

### Tray Sections

20 | Tray Section | Main Tower
21 | Tray Diameter (m) | 1.500
22 | Weir Height (m) | 5.000e-002 *
23 | Weir Length (m) | 1.200 *
24 | Tray Space (m) | 0.5500 *
25 | Tray Volume (m3) | 0.9719
26 | Disable Heat Loss Calculations | No
27 | Heat Model | None
28 | Rating Calculations | No
29 | Tray Hold Up (m3) | 8.836e-002
30 | Vessels
32 | Vessel | Reboiler | Condenser
33 | Diameter (m) | 1.193 | 1.193
34 | Length (m) | 1.789 | 1.789
35 | Volume (m3) | 2.000 * | 2.000 *
36 | Orientation | Horizontal | Horizontal
37 | Vessel has a Boot | No | No
38 | Boot Diameter (m) | --- | ---
39 | Boot Length (m) | --- | ---
40 | Hold Up (m3) | 1.000 | 1.000
41 | Other Equipment In Column Flowsheet
46 | | Pressure (atm) | Pressure Drop (kPa)
47 | Condenser | 1.000 atm * | 0.0000 kPa
48 | 1__Main Tower | 1.000 atm | 0.0000 kPa
49 | 2__Main Tower | 1.000 atm | 0.0000 kPa
50 | 3__Main Tower | 1.000 atm | 0.0000 kPa
51 | 4__Main Tower | 1.000 atm | 0.0000 kPa
52 | 5__Main Tower | 1.000 atm | 0.0000 kPa
53 | 6__Main Tower | 1.000 atm | ---
54 | Reboiler | 1.000 atm * | 0.0000 kPa
55 | Pressure Solving Options
57 | Pressure Tolerance 1.000e-004 | Pressure Drop Tolerance 1.000e-004
58 | Damping Factor 1.000 | Max Press Iterations 100
59 | CONDITIONS
Name | ORG-110 @Main | AN-NB FONDO @Main | H2-ANTORCHA @Main | H2O-NB @Main
Vapour | 0.1380 | 0.0000 | 0.9799 | 0.0000

### Aspen Technology Inc. Aspen HYSYS Version 14 Page 7 of 11

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
44 | Pressure Profile
45

56

60

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

### CONDITIONS

11 | Temperature (C) | 110.0000 * | 179.3166 | 115.0786 | 95.0945
12 | Pressure (atm) | 1.0000 * | 1.0000 | 1.0000 | 1.0000
13 | Molar Flow (kgmole/h) | 56.0413 | 41.6161 | 0.0700 | 14.3552
14 | Mass Flow (kg/h) | 4219.9744 | 3918.2059 | 1.7046 | 300.0639
15 | Std Ideal Liq Vol Flow (m3/h) | 4.0954 | 3.7954 | 0.0018 | 0.2982
16 | Molar Enthalpy (kJ/kgmole) | -2.567e+004 | 6.410e+004 | -1.870e+005 | -2.676e+005
17 | Molar Entropy (kJ/kgmole-C) | -9.918 | 4.819 | 144.8 | 21.16
18 | Heat Flow (kJ/h) | -1.4386e+06 | 2.6675e+06 | -1.3091e+04 | -3.8419e+06
19 | Name | R-T101 @Main | C-T101 @Main
20 | Vapour | --- | ---
21 | Temperature (C) | --- | ---
22 | Pressure (atm) | --- | ---
23 | Molar Flow (kgmole/h) | --- | ---
24 | Mass Flow (kg/h) | --- | ---
25 | Std Ideal Liq Vol Flow (m3/h) | --- | ---
26 | Molar Enthalpy (kJ/kgmole) | --- | ---
27 | Molar Entropy (kJ/kgmole-C) | --- | ---
28 | Heat Flow (kJ/h) | 2.0260e+06 | 1.7749e+06
29 | PROPERTIES
31 | Name | ORG-110 @Main | AN-NB FONDO @Main | H2-ANTORCHA @Main | H2O-NB @Main
32 | Molecular Weight | 75.30 | 94.15 | 24.35 | 20.90
33 | Molar Density (kgmole/m3) | 0.2265 | 9.392 | 3.203e-002 | 45.86
34 | Mass Density (kg/m3) | 17.06 | 884.2 | 0.7801 | 958.7
35 | Act. Volume Flow (m3/h) | 247.4 | 4.431 | 2.185 | 0.3130
36 | Mass Enthalpy (kJ/kg) | -340.9 | 680.8 | -7680 | -1.280e+004
37 | Mass Entropy (kJ/kg-C) | -0.1317 | 5.119e-002 | 5.944 | 1.012
38 | Heat Capacity (kJ/kgmole-C) | 156.9 | 211.4 | 45.65 | 79.50
39 | Mass Heat Capacity (kJ/kg-C) | 2.083 | 2.245 | 1.874 | 3.803
40 | LHV Molar Basis (Std) (kJ/kgmole) | 2.423e+006 | 3.222e+006 | 3.003e+005 | 1.175e+005
41 | HHV Molar Basis (Std) (kJ/kgmole) | 2.540e+006 | 3.364e+006 | 3.488e+005 | 1.621e+005
42 | HHV Mass Basis (Std) (kJ/kg) | 3.373e+004 | 3.573e+004 | 1.432e+004 | 7755
43 | CO2 Loading | --- | 0.0000 | --- | 0.0000
44 | CO2 Apparent Mole Conc. (kgmole/m3) | --- | --- | --- | ---
45 | CO2 Apparent Wt. Conc. (kgmol/kg) | --- | --- | --- | ---
46 | LHV Mass Basis (Std) (kJ/kg) | 3.218e+004 | 3.422e+004 | 1.233e+004 | 5623
47 | Phase Fraction [Vol. Basis] | 4.533e-002 | 0.0000 | 0.9264 | 0.0000
48 | Phase Fraction [Mass Basis] | 4.437e-002 | 0.0000 | 0.9110 | 0.0000
49 | Phase Fraction [Act. Vol. Basis] | 0.9828 | 0.0000 | 0.9999 | 0.0000
50 | Mass Exergy (kJ/kg) | -65.44 | -107.5 | 232.9 | 6.246
51 | Partial Pressure of CO2 (atm) | 0.0000 | 0.0000 | 0.0000 | 0.0000
52 | Cost Based on Flow (Cost/s) | 0.0000 | 0.0000 | 0.0000 | 0.0000
53 | Act. Gas Flow (ACT_m3/h) | 243.1 | --- | 2.185 | ---
54 | Avg. Liq. Density (kgmole/m3) | 13.68 | 10.96 | 38.49 | 48.14
55 | Specific Heat (kJ/kgmole-C) | 156.9 | 211.4 | 45.65 | 79.50
56 | Std. Gas Flow (STD_m3/h) | 1325 | 984.0 | 1.655 | 339.4
57 | Std. Ideal Liq. Mass Density (kg/m3) | 1030 | 1032 | 937.3 | 1006
58 | Act. Liq. Flow (m3/s) | 1.180e-003 | 1.231e-003 | 4.055e-008 | 8.694e-005
59 | Z Factor | --- | 2.868e-003 | --- | ---
60 | Watson K | 9.066 | 9.068 | 9.023 | 8.937
| User Property | --- | --- | --- | ---
| Partial Pressure of H2S (atm) | 0.0000 | 0.0000 | 0.0000 | 0.0000
| Aspen Technology Inc. Aspen HYSYS Version 14 Page 8 of 11

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

### PROPERTIES

11 | Name | ORG-110 @Main | AN-NB FONDO @Main | H2-ANTORCHA @Main | H2O-NB @Main
12 | Cp/(Cp - R) | 1.056 | 1.041 | 1.223 | 1.117
13 | Cp/Cv | 1.007 | 1.347 | 1.217 | 1.186
14 | Ideal Gas Cp/Cv | 1.080 | 1.055 | 1.237 | 1.283
15 | Ideal Gas Cp (kJ/kgmole-C) | 112.4 | 158.7 | 43.35 | 37.72
16 | Mass Ideal Gas Cp (kJ/kg-C) | 1.493 | 1.685 | 1.780 | 1.805
17 | Heat of Vap. (kJ/kgmole) | 9.329e+004 | 4.292e+004 | 6.539e+004 | 4.109e+004
18 | Kinematic Viscosity (cSt) | --- | 0.3813 | --- | 0.4065
19 | Liq. Mass Density (Std. Cond) (kg/m3) | 1034 | 1037 | 937.0 | 1028
20 | Liq. Vol. Flow (Std. Cond) (m3/h) | 4.081 | 3.777 | 1.819e-003 | 0.2920
21 | Liquid Fraction | 0.8620 | 1.000 | 2.014e-002 | 1.000
22 | Molar Volume (m3/kgmole) | 4.414 | 0.1065 | 31.22 | 2.180e-002
23 | Mass Heat of Vap. (kJ/kg) | 1239 | 455.9 | 2685 | 1966
24 | Phase Fraction [Molar Basis] | 0.1380 | 0.0000 | 0.9799 | 0.0000
25 | Surface Tension (dyne/cm) | 37.15 | 25.49 | 46.16 | ---
26 | Thermal Conductivity (W/m-K) | --- | 0.1159 | --- | 0.5930
27 | Bubble Point Pressure (atm) | 2.268 | 1.000 | 1750 | 0.9450
28 | Viscosity (cP) | --- | 0.3371 | --- | 0.3897
29 | Cv (Semi-Ideal) (kJ/kgmole-C) | 148.6 | 203.1 | 37.33 | 71.19
30 | Mass Cv (Semi-Ideal) (kJ/kg-C) | 1.973 | 2.157 | 1.533 | 3.406
31 | Cv (kJ/kgmole-C) | 155.7 | 157.0 | 37.50 | 67.06
32 | Mass Cv (kJ/kg-C) | 2.068 | 1.667 | 1.540 | 3.208
33 | Cv (Ent. Method) (kJ/kgmole-C) | --- | --- | --- | ---
34 | Mass Cv (Ent. Method) (kJ/kg-C) | --- | --- | --- | ---
35 | Cp/Cv (Ent. Method) | --- | --- | --- | ---
36 | Reid VP at 37.8 C (atm) | 1.333e-002 | 2.540e-003 | --- | 5.019e-003
37 | True VP at 37.8 C (atm) | 1.829 | 3.380e-003 | 2854 | 0.1235
38 | Liq. Vol. Flow - Sum(Std. Cond) (m3/h) | 4.079 | 3.777 | 1.821e-003 | 0.2931
39 | Viscosity Index | -0.7113 | -15.08 | -35.46 | -15.79
40 | SUMMARY
42 | Flow Basis: Molar | The composition option is selected
43 | Feed Composition
44 | | ORG-110
45 | Flow Rate (kgmole/h) | 56.0413
46 | | ---
47 | Hydrogen | 0.0001
48 | NitroBZ | 0.0302
49 | H2O | 0.2493
50 | Aniline | 0.7204
51 | Flow Basis: Molar | | The composition option is selected
52 | Feed Flows
53 | | ORG-110
54 | Flow Rate (kgmole/h) | 56.0413
55 | | ---
56 | Hydrogen (kgmole/h) | 0.0066
57 | NitroBZ (kgmole/h) | 1.6933
58 | H2O (kgmole/h) | 13.9688
59 | Aniline (kgmole/h) | 40.3727
60 | Products
| Flow Basis: Molar | | The composition option is selected
| Product Compositions
| Aspen Technology Inc. Aspen HYSYS Version 14 Page 9 of 11

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

### SUMMARY

11 | | H2 | H2O | ORG-SEP
12 | Flow Rate (kgmole/h) | 0.0700 | 14.3552 | 41.6161
13 | | --- | --- | ---
14 | Hydrogen | 0.0945 | 0.0000 | 0.0000
15 | NitroBZ | 0.0392 | 0.0045 | 0.0391
16 | H2O | 0.8167 | 0.9633 | 0.0020
17 | Aniline | 0.0496 | 0.0322 | 0.9589
18 | Flow Basis: Molar | | The composition option is selected
19 | Product Flows
20 | | H2 | H2O | ORG-SEP
21 | Flow Rate (kgmole/h) | 0.0700 | 14.3552 | 41.6161
22 | | --- | --- | ---
23 | Hydrogen (kgmole/h) | 0.0066 | 0.0000 | 0.0000
24 | NitroBZ (kgmole/h) | 0.0027 | 0.0645 | 1.6260
25 | H2O (kgmole/h) | 0.0572 | 13.8291 | 0.0825
26 | Aniline (kgmole/h) | 0.0035 | 0.4617 | 39.9075
27 | Flow Basis: Molar | | The composition option is selected
28 | Product Recoveries
29 | | H2 | H2O | ORG-SEP
30 | Flow Rate (kgmole/h) | 0.0700 | 14.3552 | 41.6161
31 | | --- | --- | ---
32 | Hydrogen (%) | 99.6967 | 0.3033 | 0.0000
33 | NitroBZ (%) | 0.1622 | 3.8070 | 96.0307
34 | H2O (%) | 0.4093 | 99.0000 | 0.5907
35 | Aniline (%) | 0.0086 | 1.1435 | 98.8479
36 | COLUMN PROFILES
38 | Reflux Ratio: 2.000 | Reboil Ratio: 0.7828 | The Flows Option is Selected | Flow Basis: Molar
39 | Column Profiles Flows
40 | | Temp (C) | Pres (atm) | Net Liq (kgmole/h) | Net Vap (kgmole/h) | Net Feed (kgmole/h) | Net Draws (kgmole/h) | Duty (kJ/h)
42 | Condenser | 95.1 | 1.000 | 28.85 | --- | --- | 14.43 | 1.77e+006 *
43 | 1__Main Tower | 94.7 | 1.000 | 73.84 | 43.28 | 56.04 | --- | ---
44 | 2__Main Tower | 94.7 | 1.000 | 73.84 | 32.23 | --- | --- | ---
45 | 3__Main Tower | 94.7 | 1.000 | 73.84 | 32.23 | --- | --- | ---
46 | 4__Main Tower | 94.7 | 1.000 | 73.78 | 32.23 | --- | --- | ---
47 | 5__Main Tower | 96.6 | 1.000 | 71.88 | 32.17 | --- | --- | ---
48 | 6__Main Tower | 134.2 | 1.000 | 74.19 | 30.26 | --- | --- | ---
49 | Reboiler | 179.3 | 1.000 | --- | 32.58 | --- | 41.62 | 2.03e+006 *
50 | Column Profiles Energy
51 | | Temperature (C) | Liq Enthalpy (kJ/kgmole) | Vap Enthalpy (kJ/kgmole) | Heat Loss (kJ/h)
53 | Condenser | 95.09 | -2.676e+005 | -1.870e+005 | ---
54 | 1__Main Tower | 94.65 | -9.017e+004 | -2.265e+005 | ---
55 | 2__Main Tower | 94.66 | -9.017e+004 | -2.265e+005 | ---
56 | 3__Main Tower | 94.66 | -9.016e+004 | -2.265e+005 | ---
57 | 4__Main Tower | 94.69 | -8.939e+004 | -2.265e+005 | ---
58 | 5__Main Tower | 96.62 | -6.038e+004 | -2.250e+005 | ---
59 | 6__Main Tower | 134.2 | 3.933e+004 | -1.646e+005 | ---
60 | Reboiler | 179.3 | 6.410e+004 | 6.989e+004 | ---
Aspen Technology Inc. | Aspen HYSYS Version 14 | Page 10 of 11

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

### FEEDS / PRODUCTS

11 | Flow Basis: Molar
12 | | Stream | Type | Duty (kJ/h) | Phase | Flows (kgmole/h) | Enthalpy (kJ/kgmole) | Temp (C)
14 | Condenser | C-T101 | Energy | 1.8e+006 * | | --- | --- | ---
15 | | H2 | Draw | --- | Vapour | 7.00e-002 * | -1.9e+005 * | 95.09 *
16 | | H2O | Draw | --- | Liquid | 14.4 * | -2.7e+005 * | 95.09 *
17 | 1__Main Tower | ORG-110 | Feed | --- | Mixed | 56.0 * | -2.6e+004 * | 110.00 *
18 | 2__Main Tower
19 | 3__Main Tower
20 | 4__Main Tower
21 | 5__Main Tower
22 | 6__Main Tower
23 | Reboiler | R-T101 | Energy | 2.0e+006 * | | --- | --- | ---
24 | | ORG-SEP | Draw | --- | Liquid | 41.6 * | 6.4e+004 * | 179.32 *
25 | PERFORMANCE SUMMARY FOR INTERNAL OPTION: Internals-1@Main Tower@COL1
27 | Number Of Stages | 6 *
28 | Total Height (m) | 3.658
29 | Total Head Loss (mm) | 437.5
30 | Total Pressure Drop (mbar) | 40.89
31 | Number Of Sections | 1
32 | Number Of Diameters | 1
33 | Pressure Drop Across Sump (kPa) | ---
34 | Section | Start | End | Height (m) | Diameter (m)
36 | CS-1 | 1__Main Tower | 6__Main Tower | 0.6096 | 0.5044
37 | Internals Type | Tray or Packing Type | Section Pressure Drop (mbar) | Approach To Flood (%) | Limiting Stage
39 | Trayed | Sieve | 40.89 | 80.00
40
Aspen Technology Inc. | Aspen HYSYS Version 14 | Page 11 of 11

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
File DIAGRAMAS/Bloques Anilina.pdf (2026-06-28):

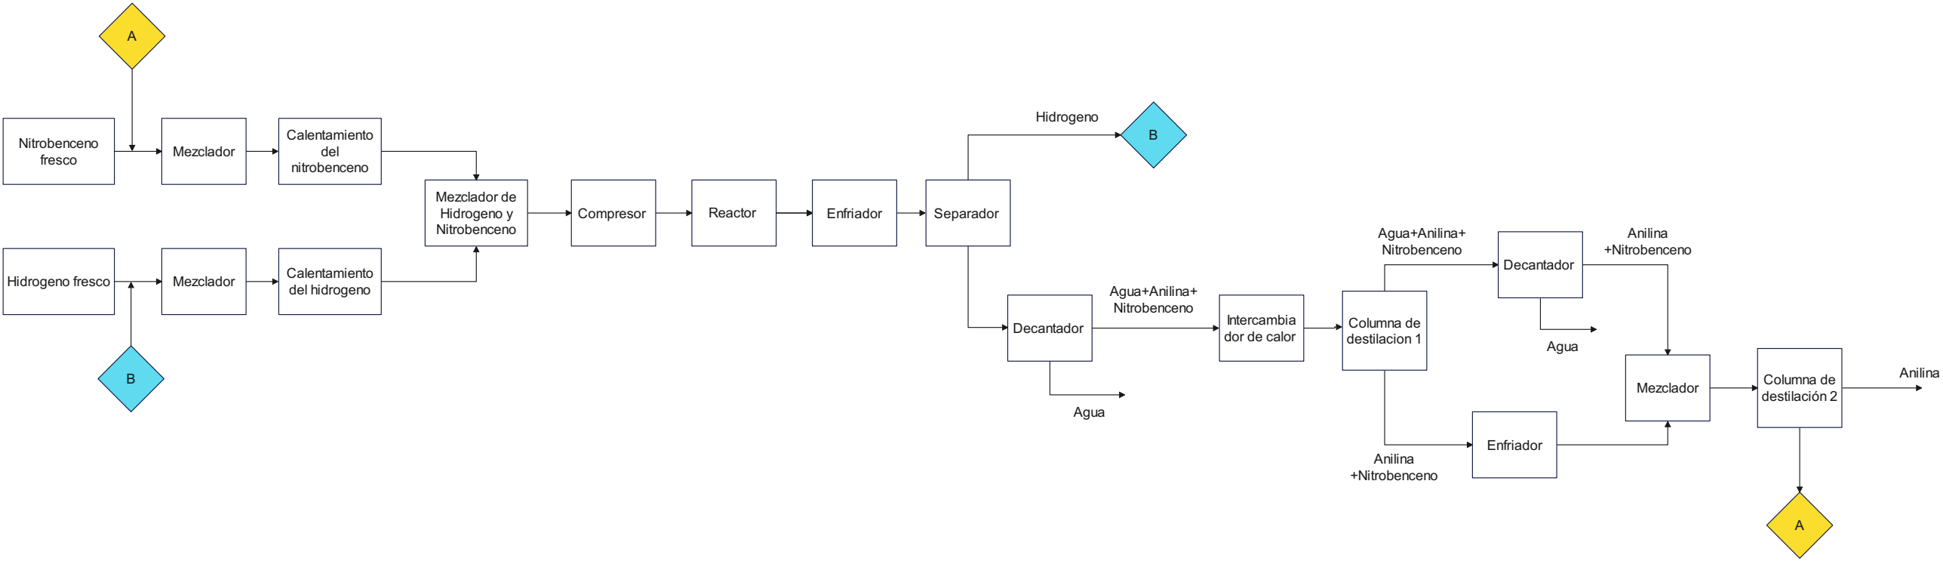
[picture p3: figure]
Nitrobenceno fresco; Hidrogeno fresco; Calentamiento del nitrobenceno; Mezclador de Hidrogeno y Nitrobenceno; Calentamiento del hidrogeno; Compresor; Reactor; Enfriador; Separador; Decantador; Hidrogeno; Columna de destilacion 1; Agua+Anilina+ Nitrobenceno; Agua; Anilina +Nitrobenceno; Columna de destilación 2; Anilina; Intercambia dor de calor; Mezclador

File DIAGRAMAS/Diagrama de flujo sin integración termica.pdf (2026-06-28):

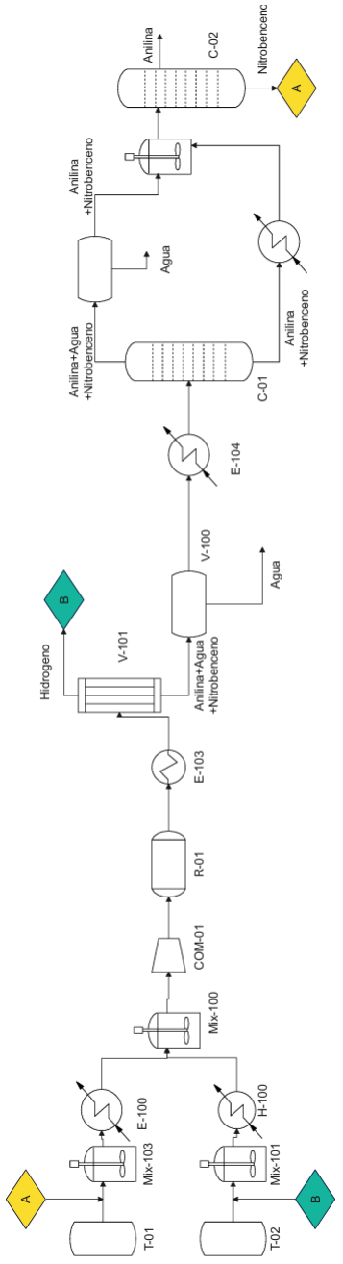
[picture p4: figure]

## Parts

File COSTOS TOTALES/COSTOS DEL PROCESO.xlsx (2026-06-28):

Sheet: Summary
Summary
Total Capital Cost [USD] | 6577850
Total Operating Cost [USD/Year] | 2739300
Total Raw Materials Cost [USD/Year] | 0
Total Product Sales [USD/Year] | 0
Total Utilities Cost [USD/Year] | 1185330
Desired Rate of Return [Percent/'Year] | 20
P.O.Period [Year] | 0
Equipment Cost [USD] | 1463800
Total Installed Cost [USD] | 4070400

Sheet: Utilities
Utilities
Name | Fluid | Rate | Rate Units | Cost per Hour | Cost Units
Electricity |  | 102.06 | KW | 7.90965 | USD/H
Cooling Water | Water | 0.10612 | MMGAL/H | 12.7344 | USD/H
Steam @100PSI | Steam | 11.393 | KLB/H | 92.73902 | USD/H
Steam @165PSI | Steam | 2.237315 | KLB/H | 21.836194 | USD/H
Servicio | Fluido | Consumo | Unidad | Costo horario
Electricidad | Electricidad | 102.06 | kW | 7.90965 USD/h
Agua de enfriamiento | Agua | 0.10612 | MMGAL/h | 12.7344 USD/h
Vapor @100 psi | Vapor | 11.393 | KLB/h | 92.73902 USD/h
Vapor @165 psi | Vapor | 2.237315 | KLB/h | 21.836194 USD/h

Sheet: Unit operation
Unit operation
Name | Equipment Cost [USD] | Installed Cost [USD] | Equipment Weight [LBS] | Installed Weight [LBS] | Utility Cost [USD/HR]
T-101 | 109500 | 535200 | 12010 | 46869 | 21.850919
E-106 | 19100 | 126600 | 1200 | 10724 | 0
T-100 | 1119100 | 2187300 | 250050 | 390817 | 91.33437
MIX-101 | 0 | 0 | 0 | 0 | 0
MIX-102 | 0 | 0 | 0 | 0 | 0
V-102 | 22300 | 168600 | 2600 | 14849 | 0
MIX-103 | 0 | 0 | 0 | 0 | 0
E-101 | 20300 | 114200 | 2300 | 15131 | 0
P-100 | 5300 | 35500 | 170 | 2407 | 0.006975
E-105 | 11600 | 82100 | 520 | 6764 | 0.396
E-103 | 27000 | 128800 | 3700 | 17471 | 5.6286
V-100 | 25500 | 144000 | 3000 | 11325 | 0
CO-100 | 0 | 0 | 0 | 0 | 0
E-100 | 26900 | 138800 | 3700 | 21814 | 0
TEE-100 | 0 | 0 | 0 | 0 | 0
RCY-1 | 0 | 0 | 0 | 0 | 0
E-104 | 11700 | 86200 | 540 | 8226 | 8.692608
MIX-100 | 0 | 0 | 0 | 0 | 0
V-101 | 25500 | 144000 | 3000 | 11325 | 0
VLV-100 | 0 | 0 | 0 | 0 | 0
RCY-2 | 0 | 0 | 0 | 0 | 0
CRV-100 | 0 | 0 | 0 | 0 | 0
H-100 | 40000 | 179100 | 6200 | 31545 | 0

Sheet: Equipment
Equipment
Name | Equipment Cost [USD] | Installed Cost [USD] | Equipment Weight [LBS] | Total Installed Weight [LBS] | Sizing Errors | Evaluation Errors
E-106 | 19100 | 126600 | 1200 | 10724
MIX-101 | 0 | 0 | 0 | 0
MIX-102 | 0 | 0 | 0 | 0
V-102 | 22300 | 168600 | 2600 | 14849
MIX-103 | 0 | 0 | 0 | 0
E-101 | 20300 | 114200 | 2300 | 15131
P-100 | 5300 | 35500 | 170 | 2407
E-105 | 11600 | 82100 | 520 | 6764
E-103 | 27000 | 128800 | 3700 | 17471
V-100 | 25500 | 144000 | 3000 | 11325
CO-100 | 0 | 0 | 0 | 0 |  | ERROR> 'GC - 21' INLET TEMPERATURE IS OUT OF RANGE
E-100 | 26900 | 138800 | 3700 | 21814
TEE-100 | 0 | 0 | 0 | 0
RCY-1 | 0 | 0 | 0 | 0
E-104 | 11700 | 86200 | 540 | 8226
MIX-100 | 0 | 0 | 0 | 0
V-101 | 25500 | 144000 | 3000 | 11325
VLV-100 | 0 | 0 | 0 | 0
RCY-2 | 0 | 0 | 0 | 0
H-100 | 40000 | 179100 | 6200 | 31545
Main Tower_@T-101 | 48800 | 229700 | 5100 | 19998
Condenser_@T-101-cond acc | 18400 | 148400 | 2100 | 11921
Condenser_@T-101-overhead split | 0 | 0 | 0 | 0
Condenser_@T-101-reflux pump | 6000 | 36200 | 210 | 2447
Reboiler_@T-101-bottoms split | 0 | 0 | 0 | 0
Reboiler_@T-101-reb | 36300 | 120900 | 4600 | 12503
Main Tower_@T-100 | 1025300 | 1721900 | 238700 | 343675
Condenser_@T-100-cond | 21000 | 103700 | 2500 | 10938
Condenser_@T-100-cond acc | 25000 | 156100 | 3200 | 13116
Condenser_@T-100-overhead split | 0 | 0 | 0 | 0
Condenser_@T-100-reflux pump | 8100 | 54700 | 350 | 4718
Reboiler_@T-100-bottoms split | 0 | 0 | 0 | 0
Reboiler_@T-100-reb | 39700 | 150900 | 5300 | 18370

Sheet: TEMA HEX
TEMA HEX
Item description | E-106 | E-101 | E-105 | E-103 | E-100 | E-104 | H-100 | Condenser_@T-101-cond | Condenser_@T-100-cond
User tag number | HE2 | HE12 | HE14 | HE19 | HE22 | HE29 | HE35 | HE6 | HE15
Remarks 1 | Equipment mapped from 'E-106'. | Equipment mapped from 'E-101'. | Equipment mapped from 'E-105'. | Equipment mapped from 'E-103'. | Equipment mapped from 'E-100'. | Equipment mapped from 'E-104'. | Equipment mapped from 'H-100'. | Equipment mapped from 'Condenser_@T-101'. | Equipment mapped from 'Condenser_@T-100'.
Quoted cost per item [USD]
Currency unit for matl cost
Number of identical items | 1 | 1 | 1 | 1 | 1 | 1 | 1 |  | 1
Installation option
Heat transfer area [m2] | 13.24017673 | 27.47565676 | 3.072713436 | 51.91484282 | 50.93195383 | 3.611530395 | 107.9041741 |  | 34.73525163
Number of shells
Front end TEMA symbol | B | B | B | B | B | B | B |  | B
Shell TEMA symbol | E | E | E | E | E | E | E |  | E
Rear end TEMA symbol | M | M | M | M | M | M | M |  | M
Heat exchanger design option
Tube material
Tube design gauge pressure [kPag] | 571.0460788 | 571.0460788 | 415.79608 | 415.79608 | 243.42108 | 760.54608 | 243.42108 |  | 415.79608
Tube design temperature [C] | 523.50532 | 367.7777778 | 207.0944028 | 277.7777778 | 343.3333333 | 192.1111111 | 343.3333333 |  | 123.0956756
Tube operating temperature [C] | 495.7275422 | 340 | 35 | 35 | 315.5555556 | 164.3333333 | 315.5555556 |  | 35
Tube outside diameter [m] | 0.0254 | 0.0254 | 0.0254 | 0.0254 | 0.0254 | 0.0254 | 0.0254 |  | 0.0254
Shell material
Shell design gauge pressure [kPag] | 346.9210769 | 346.9210769 | 243.42108 | 571.0460788 | 128.504411 | 473.254411 | 128.504411 |  | 243.42108
Shell design temperature [C] | 238.9826939 | 253.95869 | 207.0944028 | 277.7777778 | 337.7777778 | 137.7777778 | 337.7777778 |  | 123.0956756
Shell operating temperature [C] | 211.2049161 | 226.1809122 | 179.316625 | 250 | 310 | 110 | 310 |  | 95.31789778
Tube side pipe material
Shell side pipe material
Number of tubes per shell
Tube length extended [m] | 6.096 | 6.096 | 6.096 | 6.096 | 6.096 | 6.096 | 6.096 |  | 6.096
Tube gauge
Tube pitch [m] | 0.03175 | 0.03175 | 0.03175 | 0.03175 | 0.03175 | 0.03175 | 0.03175 |  | 0.03175
Shell diameter [m]
Shell wall thickness [m]
Shell corrosion allowance [m]
Expansion joint
Tube sheet material
Number of tube passes | 1 | 1 | 1 | 1 | 1 | 1 | 1 |  | 1
Number of shell passes | 1 | 1 | 1 | 1 | 1 | 1 | 1 |  | 1
Heat exchanger design tool
Allow resize

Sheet: Quoted equipment
Quoted equipment
Item description | MIX-101 | MIX-102 | MIX-103 | TEE-100 | RCY-1 | MIX-100 | VLV-100 | RCY-2 | Condenser_@T-101-overhead split | Reboiler_@T-101-bottoms split | Condenser_@T-100-overhead split | Reboiler_@T-100-bottoms split
User tag number | C3 | C4 | C10 | C23 | C28 | C30 | C32 | C33 | C8 | C24 | C17 | C26
Remarks 1 | Equipment mapped from 'MIX-101'. | Equipment mapped from 'MIX-102'. | Equipment mapped from 'MIX-103'. | Equipment mapped from 'TEE-100'. | Equipment mapped from 'RCY-1'. | Equipment mapped from 'MIX-100'. | Equipment mapped from 'VLV-100'. | Equipment mapped from 'RCY-2'. | Equipment mapped from 'Condenser_@T-101'. | Equipment mapped from 'Reboiler_@T-101'. | Equipment mapped from 'Condenser_@T-100'. | Equipment mapped from 'Reboiler_@T-100'.
Code of account | 100 | 100 | 100 | 100 | 100 | 100 | 100 | 100 | 100 | 100 | 100 | 100
Icarus/User COA option
Material cost per unit | 0 | 0 | 0 | 0 | 0 | 0 | 0 | 0 | 0 | 0 | 0 | 0
Currency unit for matl cost
Labor hours per unit [seconds]
Number of identical items
Installation option
Unit of measure
Quantity
Quantity adjustment option
Item classification
Item type
Material
Component weight [kg]
ID in bulk report
Allow resize

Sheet: Vertical vessel
Vertical vessel
Item description | V-102 | V-100 | V-101
User tag number | VT5 | VT20 | VT31
Remarks 1 | Equipment mapped from 'V-102'. | Equipment mapped from 'V-100'. | Equipment mapped from 'V-101'.
Quoted cost per item [USD]
Currency unit for matl cost
Number of identical items
Installation option
Application
Shell material
Liquid volume [m3] | 2.401932948 | 3.269297609 | 3.269297609
Vessel diameter [m] | 0.9144 | 1.0668 | 1.0668
Vessel tangent to tangent height [m] | 3.6576 | 3.6576 | 3.6576
Design gauge pressure [kPag] | 103.425 | 243.42108 | 243.42108
Vacuum design gauge pressure [kPag]
Design temperature [C] | 122.8722439 | 121.1111111 | 121.1111111
Operating temperature [C] | 95.09446611 | 30 | 30
Skirt height [m]
Vessel leg height [m]
Wind or seismic design
Fluid volume [%]
Base material thickness [m]
Corrosion allowance [m]
Cladding material
Cladding thickness [m]
Head type
ASME design basis
Allow resize

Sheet: Centrif pump
Centrif pump
Item description | P-100 | Condenser_@T-101-reflux pump | Condenser_@T-100-reflux pump
User tag number | CP13 | CP9 | CP18
Remarks 1 | Equipment mapped from 'P-100'. | Equipment mapped from 'Condenser_@T-101'. | Equipment mapped from 'Condenser_@T-100'.
Quoted cost per item [USD]
Currency unit for matl cost
Number of identical items
Installation option
Casing material
Liquid flow rate [m3/h] | 0.1068348173 | 0.6627189816 | 21.81813645
Fluid head [m] | 8.820684619
Speed
Fluid specific gravity | 1.102643 | 1.000431 | 0.967615
Driver power [hp]
Driver type
Seal type
Design gauge pressure [kPag] | 103.425 | 103.425 | 103.425
Design temperature [C] | 145.6731939 | 122.8722439 | 121.1111111
Fluid viscosity [cP] | 0.728 | 0.5 | 0.5
Pump efficiency [%] | 75 | 70 | 70
Allow resize

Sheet: Centrif gas compr
Centrif gas compr
Item description | CO-100
User tag number | GC21
Remarks 1 | Equipment mapped from 'CO-100'.
Quoted cost per item [USD]
Currency unit for matl cost
Number of identical items
Installation option
Casing material
Actual gas flow rate Inlet [ACT_m3/h] | 13443.27885
Design gauge pressure Inlet [kPag] | -0.003923255
Design temperature Inlet [C] | 309.9999972
Design gauge pressure Outlet [kPag] | 398.6710788
Compressor speed
Driver power [hp] | 1098.933432
Molecular weight | 22.264554
Specific heat ratio | 1.166273
Compressibility factor Inlet | 1
Compressibility factor Outlet | 1
Driver type | MOTOR
Turbine gauge pressure [kPag]
Lube oil system
Allow resize

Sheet: Agitated reactor
Agitated reactor
Item description | CRV-100
User tag number | AT34
Remarks 1 | Equipment mapped from 'CRV-100'.
Quoted cost per item [USD]
Currency unit for matl cost
Number of identical items
Installation option
Application
Shell material
Liquid volume [m3]
Vessel diameter [m]
Vessel tangent to tangent height [m]
Design gauge pressure [kPag]
Vacuum design gauge pressure [kPag]
Design temperature [C]
Operating temperature [C]
Jacket design gauge pressure [kPag]
Jacket type
Jacket material
Agitator power [hp]
Driver type
Cladding material
Skirt or leg height [m]
Base material thickness [m]
Corrosion allowance [m]
Cladding thickness [m]
Fluid depth [m]
Fluid density [kg/m3]
Fluid viscosity [cP]
Impeller type
Impeller diameter [m]
Number of impellers
Impeller speed
Reynolds number
Power function
Allow resize

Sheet: Multi-diameter tower
Multi-diameter tower
Item description | Main Tower_@T-101 | Main Tower_@T-100
User tag number | TW1 | TW11
Remarks 1 | Equipment mapped from 'Main Tower_@T-101'. | Equipment mapped from 'Main Tower_@T-100'.
Quoted cost per item [USD]
Currency unit for matl cost
Number of identical items
Installation option
Application
Base material Bottom
Diameter Bottom section [m] | 0.6096 | 3.81
Bottom tangent to tangent height [m] | 7.3152 | 38.4048
Design gauge pressure Bottom [kPag] | 103.425 | 103.425
Design temperature Bottom [C] | 161.9347789 | 145.5781906
Operating temperature Bottom [C] | 134.1570011 | 117.8004128
Number of trays Bottom section | 6 | 57
Bottom Tray type | SIEVE | SIEVE
Bottom Tray material
Bottom Tray spacing [m] | 0.6096 | 0.6096
Bottom Packing material Section1
Packing height Bottom Section1 [m]
Bottom Packing material Section2
Packing height Bottom Section2 [m]
Cladding material Bottom
Cladding thickness Bottom [m]
Thickness Bottom section [m]
Corrosion allowance Bottom [m]
Base material Middle
Diameter Middle section [m]
Middle tangent to tangent height [m]
Design gauge pressure Middle [kPag]
Design temperature Middle [C]
Operating temperature Middle [C]
Number of trays Middle section
Middle Tray type
Middle Tray material
Middle Tray spacing [m]
Middle Packing material Section1
Packing height Middle Section1 [m]
Middle Packing material Section2
Packing height Middle Section2 [m]
Cladding material Middle
Cladding thickness Middle [m]
Thickness Middle section [m]
Corrosion allowance Middle [m]
Base material Top
Diameter Top section [m]
Top tangent to tangent height [m]
Design gauge pressure Top [kPag]
Design temperature Top [C]
Operating temperature Top [C]
Number of trays Top section
Top Tray type
Top Tray material
Top Tray spacing [m]
Top Packing material Section1
Packing height Top Section1 [m]
Top Packing material Section2
Packing height Top Section2 [m]
Cladding material Top
Cladding thickness Top [m]
Thickness Top section [m]
Corrosion allowance Top [m]
Skirt height [m]
Wind or seismic design
Fluid volume [%]
Vacuum design gauge pressure [kPag]
Transition height 1 [m]
Transition height 2 [m]
Molecular Wt Overhead Prod. | 20.90833 | 93.488677
ASME design basis
Allow Resize

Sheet: Horizontal drum
Horizontal drum
Item description | Condenser_@T-101-cond acc | Condenser_@T-100-cond acc
User tag number | HT7 | HT16
Remarks 1 | Equipment mapped from 'Condenser_@T-101'. | Equipment mapped from 'Condenser_@T-100'.
Quoted cost per item [USD]
Currency unit for matl cost
Number of identical items
Installation option
Application
Shell material
Liquid volume [m3] | 1.801449698 | 2.724414673
Vessel diameter [m] | 0.9144 | 1.0668
Vessel tangent to tangent length [m] | 2.7432 | 3.048
Design gauge pressure [kPag] | 103.425 | 103.425
Vacuum design gauge pressure [kPag] |  | -100.667
Design temperature [C] | 122.8722439 | 121.1111111
Operating temperature [C] | 95.09446611 | 89.08493111
Cladding material
Diameter of drip leg [m]
Length of drip leg [m]
Base material thickness [m]
Corrosion allowance [m]
Cladding thickness [m]
Head type
Allow resize

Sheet: U-Tube reboiler
U-Tube reboiler
Item description | Reboiler_@T-101-reb | Reboiler_@T-100-reb
User tag number | RB25 | RB27
Remarks 1 | Equipment mapped from 'Reboiler_@T-101'. | Equipment mapped from 'Reboiler_@T-100'.
Quoted cost per item [USD]
Currency unit for matl cost
Number of identical items | 1 | 1
Installation option
Heat transfer area [m2] | 51.90180132 | 66.25529272
Number of shells
Heat exchanger design option
Tube material
Tube design gauge pressure [kPag] | 1208.72108 | 760.54608
Tube design temperature [C] | 212 | 192.1111111
Tube operating temperature [C] | 184.2222222 | 164.3333333
Tube outside diameter [m] | 0.0254 | 0.0254
Shell material
Shell design gauge pressure [kPag] | 772.037749 | 473.254411
Shell design temperature [C] | 207.0944028 | 145.5782039
Shell operating temperature [C] | 179.316625 | 117.8004261
Tube side pipe material
Shell side pipe material
Number of tubes per shell
Tube length extended [m] | 6.096 | 6.096
Tube gauge
Tube pitch [m] | 0.03175 | 0.03175
Tube pitch symbol | TRIANGULAR | TRIANGULAR
Shell diameter [m]
Tube port diameter [m]
Shell wall thickness [m]
Shell corrosion allowance [m]
Tube sheet material
Number of tube passes | 2 | 2
Duty [kJ/h] | 2025991.278 | 9678768.854
Vaporization [%]
Specific gravity tower bottoms
Molecular weight Bottoms
Heat of vaporization [kJ/kgmole]
TEMA type | BKU | BKU
Heat exchanger design tool
Allow resize

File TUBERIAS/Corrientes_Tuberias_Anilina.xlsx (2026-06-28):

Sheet: Corrientes
Tabla ordenada de corrientes de tubería – Planta de Anilina
No. | Stream Name | Clasificación | Flow Margin [%] | Pipe Material | Schedule | Pipe Nominal Diameter
1 | ANILINA-NB-SEP | Nitrobenceno / mezcla orgánica | 0 | Carbon Steel | 40 | 6 mm
2 | AN-NB FONDO | Nitrobenceno / mezcla orgánica | 0 | Carbon Steel | 40 | 40 mm
3 | AN-NB MIXED | Nitrobenceno / mezcla orgánica | 0 | Carbon Steel | 40 | 40 mm
4 | AN-NB-110 | Nitrobenceno / mezcla orgánica | 0 | Carbon Steel | 40 | 40 mm
5 | GAS-250 | Gas / hidrógeno | 0 | Stainless Steel | 40S | 200 mm
6 | GAS-30 | Gas / hidrógeno | 0 | Stainless Steel | 40S | 125 mm
7 | GAS-5BAR | Gas / hidrógeno | 0 | Stainless Steel | 40S | 250 mm
8 | GAS-340 | Gas / hidrógeno | 0 | Stainless Steel | 40S | 200 mm
9 | H2 TOTAL | Gas / hidrógeno | 0 | Stainless Steel | 40S | 300 mm
10 | H2-1ATM | Gas / hidrógeno | 0 | Stainless Steel | 40S | 200 mm
11 | H2-310 | Gas / hidrógeno | 0 | Stainless Steel | 10S | 400 mm
12 | H2-ANTORCHA | Gas / hidrógeno | 0 | Stainless Steel | 40S | 10 mm
13 | H2-FRESH | Gas / hidrógeno | 0 | Stainless Steel | 40S | 250 mm
14 | H2-HOT | Gas / hidrógeno | 0 | Stainless Steel | 10S | 400 mm
15 | H2O-FONDO_1 | Agua / fase acuosa | 0 | Carbon Steel | 40 | 25 mm
16 | H2O-FONDO_2 | Agua / fase acuosa | 0 | Carbon Steel | 40 | 15 mm
17 | H2O-NB | Agua / fase acuosa | 0 | Carbon Steel | 40 | 15 mm
18 | H2-SPLIT | Gas / hidrógeno | 0 | Stainless Steel | 40S | 125 mm
19 | LIQ-SPLIT | Líquido orgánico | 0 | Carbon Steel | 40 | 50 mm
20 | MIX-GAS | Gas / hidrógeno | 0 | Stainless Steel | 10S | 450 mm
21 | NB Fresh | Nitrobenceno / mezcla orgánica | 0 | Carbon Steel | 40 | 50 mm
22 | NB-310 | Nitrobenceno / mezcla orgánica | 0 | Carbon Steel | 40 | 200 mm
23 | NB-HOT | Nitrobenceno / mezcla orgánica | 0 | Carbon Steel | 40 | 150 mm
24 | NB-MIX | Nitrobenceno / mezcla orgánica | 0 | Carbon Steel | 40 | 50 mm
25 | NBZ-REC | Nitrobenceno / mezcla orgánica | 0 | Carbon Steel | 40 | 10 mm
26 | ORG-110 | Líquido orgánico | 0 | Carbon Steel | 40 | 250 mm
27 | ORGANICA | Líquido orgánico | 0 | Carbon Steel | 40 | 40 mm
28 | PURGA-ANTORCHA | Gas / hidrógeno | 0 | Stainless Steel | 40S | 80 mm
29 | REC | Recirculación | 0 | Stainless Steel | 40S | 200 mm
30 | REC-H2 | Gas / hidrógeno | 0 | Stainless Steel | 40S | 200 mm
31 | RX-OUT | Proceso | 0 | Stainless Steel | 40S | 200 mm
32 | NBZ | Nitrobenceno / mezcla orgánica | 0 | Carbon Steel | 40 | 10 mm
33 | ANILINA | Anilina / producto | 0 | Carbon Steel | 40 | 40 mm
34 | NBZ 1ATM | Nitrobenceno / mezcla orgánica | 0 | Carbon Steel | 40 | 10 mm

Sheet: Resumen
Resumen de materiales, schedules y diámetros
Pipe Material | Cantidad | Schedule | Cantidad
Carbon Steel | 18 | 40 | 18
Stainless Steel | 16 | 10S | 3
 |  | 40S | 13
Diámetro nominal | Cantidad | Nota
6 mm | 1 | Se eliminaron las terminaciones '@Main' de todos los nombres de corriente.
10 mm | 4 | La columna 'Clasificación' se agregó para ordenar visualmente las corrientes por tipo.
15 mm | 2 | Los valores de Flow Margin se conservaron en 0 %, tal como fueron proporcionados.
25 mm | 1 | El archivo mantiene los nombres técnicos originales de las corrientes.
40 mm | 5
50 mm | 3
80 mm | 1
125 mm | 2
150 mm | 1
200 mm | 7
250 mm | 3
300 mm | 1
400 mm | 2
450 mm | 1

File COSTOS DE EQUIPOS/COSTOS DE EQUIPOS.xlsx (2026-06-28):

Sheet: Equipos con costo
Equipos con valores numéricos de costo y peso
No. | Name | Tipo de equipo | Equipment Cost [USD] | Installed Cost [USD] | Equipment Weight [LBS] | Total Installed Weight [LBS]
1 | E-106 | Intercambiador | 19100 | 126600 | 1200 | 10724
2 | V-102 | Recipiente / separador | 22300 | 168600 | 2600 | 14849
3 | E-101 | Intercambiador | 20300 | 114200 | 2300 | 15131
4 | P-100 | Bomba | 5300 | 35500 | 170 | 2407
5 | E-105 | Intercambiador | 11600 | 82100 | 520 | 6764
6 | E-103 | Intercambiador | 27000 | 128800 | 3700 | 17471
7 | V-100 | Recipiente / separador | 25500 | 144000 | 3000 | 11325
8 | E-100 | Intercambiador | 26900 | 138800 | 3700 | 21814
9 | E-104 | Intercambiador | 11700 | 86200 | 540 | 8226
10 | V-101 | Recipiente / separador | 25500 | 144000 | 3000 | 11325
11 | H-100 | Calentador | 40000 | 179100 | 6200 | 31545
12 | Main Tower_@T-101 | Columna | 48800 | 229700 | 5100 | 19998
13 | Condenser_@T-101-cond acc | Condensador | 18400 | 148400 | 2100 | 11921
14 | Condenser_@T-101-reflux pump | Bomba | 6000 | 36200 | 210 | 2447
15 | Reboiler_@T-101-reb | Rehervidor | 36300 | 120900 | 4600 | 12503
16 | Main Tower_@T-100 | Columna | 1025300 | 1721900 | 238700 | 343675
17 | Condenser_@T-100-cond | Condensador | 21000 | 103700 | 2500 | 10938
18 | Condenser_@T-100-cond acc | Condensador | 25000 | 156100 | 3200 | 13116
19 | Condenser_@T-100-reflux pump | Bomba | 8100 | 54700 | 350 | 4718
20 | Reboiler_@T-100-reb | Rehervidor | 39700 | 150900 | 5300 | 18370
 |  | TOTAL | 1463800 | 4070400 | 288990 | 589267

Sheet: Resumen
Resumen de equipos filtrados
Indicador | Valor | Tipo de equipo | Cantidad | Costo instalado [USD]
Equipos originales | 33 | Bomba | 3 | 126400
Equipos eliminados por costo/peso cero | 13 | Calentador | 1 | 179100
Equipos con valores numéricos | 20 | Columna | 2 | 1951600
Costo total de equipo [USD] | 1463800 | Condensador | 3 | 408200
Costo total instalado [USD] | 4070400 | Intercambiador | 6 | 676700
 |  | Recipiente / separador | 3 | 456600
 |  | Rehervidor | 2 | 271800

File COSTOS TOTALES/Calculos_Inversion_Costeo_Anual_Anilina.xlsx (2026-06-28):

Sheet: Resumen
Resumen económico — Planta de anilina
Concepto | Valor | Unidad | Base de operación | Valor
Inversión total requerida | 4070400.00 | USD | Días/año | 350
Costo anual de materias primas | 57161700.00 | USD/año | Horas/día | 24
Costo anual de servicios auxiliares | 1135841.82 | USD/año | Horas/año | 8400
Costeo anual total de la planta | 58297541.82 | USD/año
Texto resumen para reporte
La inversión total requerida de la planta se estimó tomando como base el costo total instalado de los equipos principales, obteniéndose un valor de 4,070,400 USD. El costeo anual de la planta se calculó a partir del costo anual de materias primas y servicios auxiliares. Las materias primas representan 57,161,700 USD/año, mientras que los servicios auxiliares representan 1,135,841.82 USD/año. Por lo tanto, el costeo anual total estimado para la operación de la planta es de 58,297,541.82 USD/año.

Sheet: Inversión requerida
Total de inversión requerido de la planta
Concepto | Valor [USD] | Criterio | Se usa para inversión | Observación
Costo total de equipo | 1463800 | Costo base de adquisición | No | Dato de equipos costeados
Costo total instalado | 4070400 | Costo de equipo + instalación | Sí | Representa la inversión preliminar de equipos principales
Resultado | Fórmula | Total [USD] | Unidad | Comentario
Inversión total requerida | Costo total instalado | 4070400 | USD | Inversión preliminar de los equipos principales instalados
Interpretación
El valor de inversión requerido corresponde al costo total instalado de los equipos principales costeados por Aspen HYSYS.
No representa la inversión total definitiva del proyecto, ya que no incluye terreno, obra civil, ingeniería detallada, permisos, contingencias ni capital de trabajo.

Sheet: Costeo anual
Costeo anual de la planta
Costo anual de materias primas
Materia prima | Proveedor | Cantidad | Unidad cantidad | Precio unitario | Unidad precio | Costo anual [USD/año]
Nitrobenceno | Wanhua Chemical | 43041.60 | ton/año | 1175.00 | USD/ton | 50573880.00
Hidrógeno | Linde México | 2286.48 | ton/año | 2.75 | USD/kg | 6287820.00
Paladio soportado en alúmina | BADF Catalisys | 5.00 | ton/año | 60.00 | USD/kg | 300000.00
 |  |  |  |  | Total materias primas | 57161700.00
Costo anual de servicios auxiliares
Servicio auxiliar | Costo horario | Unidad | Horas/año | Fuente horas | Costo anual [USD/año] | Comentario
Electricidad | 7.91 | USD/h | 8400 | Supuestos!B7 | 66441.06 | Consumo eléctrico de equipos
Agua de enfriamiento | 12.73 | USD/h | 8400 | Supuestos!B7 | 106968.96 | Servicio de enfriamiento
Vapor @100 psi | 92.74 | USD/h | 8400 | Supuestos!B7 | 779007.77 | Servicio térmico principal
Vapor @165 psi | 21.84 | USD/h | 8400 | Supuestos!B7 | 183424.03 | Servicio térmico secundario
 |  |  |  | Total servicios auxiliares | 1135841.82
Costeo anual total de la planta
Concepto | Valor [USD/año] | Porcentaje del total | Comentario
Costo anual de materias primas | 57161700.00 | 98.05% | Suma de nitrobenceno, hidrógeno y catalizador
Costo anual de servicios auxiliares | 1135841.82 | 1.95% | Suma de electricidad, agua de enfriamiento y vapor
Costeo anual total de la planta | 58297541.82 | 100.00% | Materias primas + servicios auxiliares

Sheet: Supuestos
Supuestos base para el cálculo económico
Concepto | Valor | Unidad | Comentario
Días de operación al año | 350 | días/año | Base de operación continua del proyecto
Horas de operación por día | 24 | h/día | Operación continua
Horas de operación al año | 8400 | h/año | Calculado como días de operación × horas por día
Nota
Los cálculos se realizaron con base en los datos del archivo del proyecto: inversión por equipos principales instalados, costos anuales de materias primas y costos horarios de servicios auxiliares. No se incluyen terreno, obra civil, ingeniería detallada, permisos, contingencias ni capital de trabajo.

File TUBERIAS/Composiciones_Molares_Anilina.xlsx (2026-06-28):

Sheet: Composiciones
Tabla ordenada de composiciones molares – Planta de Anilina
No. | Stream Name | Clasificación | Hydrogen | NitroBZ | H2O | Aniline | Suma | Componente dominante | Desviación vs 1
1 | NB Fresh | Nitrobenceno / orgánica | 0.000000000 | 1.000000000 | 0.000000000 | 0.000000000 | 1.000000000 | NitroBZ | 0
2 | H2-FRESH | Gas / hidrógeno | 1.000000000 | 0.000000000 | 0.000000000 | 0.000000000 | 1.000000000 | Hydrogen | 0
3 | NB-310 | Nitrobenceno / orgánica | 2.0477e-32 | 0.999999962 | 2.0477e-32 | 0.000000038 | 1.000000000 | NitroBZ | 4.861999692e-10
4 | H2-310 | Gas / hidrógeno | 0.992138285 | 0.000011606 | 0.007637290 | 0.000212820 | 1.000000001 | Hydrogen | 8.000000662e-10
5 | MIX-GAS | Gas / hidrógeno | 0.827215286 | 0.166239520 | 0.006367744 | 0.000177449 | 0.999999999 | Hydrogen | 9.999999717e-10
6 | GAS-5BAR | Gas / hidrógeno | 0.827215286 | 0.166239520 | 0.006367744 | 0.000177449 | 0.999999999 | Hydrogen | 9.999999717e-10
7 | GAS-340 | Gas / hidrógeno | 0.827215286 | 0.166239520 | 0.006367744 | 0.000177449 | 0.999999999 | Hydrogen | 9.999999717e-10
8 | RX-OUT | Proceso | 0.414613633 | 0.007912305 | 0.387367594 | 0.190106469 | 1.000000001 | Hydrogen | 1.000000083e-09
9 | GAS-250 | Gas / hidrógeno | 0.414613633 | 0.007912305 | 0.387367594 | 0.190106469 | 1.000000001 | Hydrogen | 1.000000083e-09
10 | GAS-30 | Gas / hidrógeno | 0.414613633 | 0.007912305 | 0.387367594 | 0.190106469 | 1.000000001 | Hydrogen | 1.000000083e-09
11 | H2-SPLIT | Gas / hidrógeno | 0.978549843 | 0.000031665 | 0.020837827 | 0.000580665 | 1.000000001 | Hydrogen | 5.000000414e-10
12 | LIQ-SPLIT | Fase orgánica / líquida | 0.000068845 | 0.013705297 | 0.656800557 | 0.329425300 | 0.999999999 | H2O | 6.000000496e-10
13 | ORG-110 | Fase orgánica / líquida | 0.000118374 | 0.030214428 | 0.249258028 | 0.720409170 | 1.000000000 | Aniline | 0
14 | AN-NB FONDO | Nitrobenceno / orgánica | 1.16818e-29 | 0.039072547 | 0.001982786 | 0.958944667 | 1.000000000 | Aniline | 0
15 | H2O-NB | Fase acuosa | 0.000001402 | 0.004490540 | 0.963346863 | 0.032161194 | 0.999999999 | H2O | 1.159999985e-09
16 | AN-NB-110 | Nitrobenceno / orgánica | 1.16818e-29 | 0.039072547 | 0.001982786 | 0.958944667 | 1.000000000 | Aniline | 0
17 | H2-ANTORCHA | Gas / hidrógeno | 0.094481306 | 0.039242571 | 0.816699502 | 0.049576621 | 1.000000000 | H2O | 0
18 | ORGANICA | Fase orgánica / líquida | 0.000118374 | 0.030214428 | 0.249258028 | 0.720409170 | 1.000000000 | Aniline | 0
19 | H2O-FONDO_1 | Fase acuosa | 0.000027881 | 0.000050841 | 0.993872929 | 0.006048349 | 1.000000000 | H2O | 1.000000083e-10
20 | ANILINA-NB-SEP | Producto / anilina | 0.000014484 | 0.175559676 | 0.134153019 | 0.690272821 | 1.000000000 | Aniline | 0
21 | H2O-FONDO_2 | Fase acuosa | 0.000001080 | 0.000280367 | 0.983754108 | 0.015964445 | 1.000000000 | H2O | 1.200000099e-10
22 | H2-1ATM | Gas / hidrógeno | 0.978549843 | 0.000031665 | 0.020837827 | 0.000580665 | 1.000000001 | Hydrogen | 5.000000414e-10
23 | H2 TOTAL | Gas / hidrógeno | 0.992138285 | 0.000011606 | 0.007637290 | 0.000212820 | 1.000000001 | Hydrogen | 8.000000662e-10
24 | REC-H2 | Gas / hidrógeno | 0.978549843 | 0.000031666 | 0.020837827 | 0.000580665 | 1.000000001 | Hydrogen | 6.000000496e-10
25 | PURGA-ANTORCHA | Gas / hidrógeno | 0.978549843 | 0.000031666 | 0.020837827 | 0.000580665 | 1.000000001 | Hydrogen | 6.000000496e-10
26 | REC | Recirculación | 0.978549843 | 0.000031666 | 0.020837827 | 0.000580665 | 1.000000001 | Hydrogen | 6.000000496e-10
27 | AN-NB MIXED | Nitrobenceno / orgánica | 0.000000119 | 0.040194117 | 0.003068882 | 0.956736882 | 1.000000000 | Aniline | 2.099986851e-11
28 | NB-HOT | Nitrobenceno / orgánica | 2.0477e-32 | 0.999999962 | 2.0477e-32 | 0.000000038 | 1.000000000 | NitroBZ | 4.861999692e-10
29 | H2-HOT | Gas / hidrógeno | 0.992138285 | 0.000011606 | 0.007637290 | 0.000212820 | 1.000000001 | Hydrogen | 8.000000662e-10
30 | NBZ-REC | Nitrobenceno / orgánica | 1.0004e-30 | 0.999998120 | 1.0004e-30 | 0.000001880 | 1.000000000 | NitroBZ | 2.400000199e-10
31 | NB-MIX | Nitrobenceno / orgánica | 2.0477e-32 | 0.999999962 | 2.0477e-32 | 0.000000038 | 1.000000000 | NitroBZ | 4.861999692e-10
32 | ANILINA | Producto / anilina | 0.000000121 | 0.019858978 | 0.003133900 | 0.977007001 | 1.000000000 | Aniline | 3.58000074e-10
33 | NBZ | Nitrobenceno / orgánica | 1.3079e-143 | 0.999998121 | 9.9969e-31 | 0.000001879 | 1.000000000 | NitroBZ | 1.400000116e-10
34 | NBZ 1ATM | Nitrobenceno / orgánica | 1.3079e-143 | 0.999998121 | 9.9969e-31 | 0.000001879 | 1.000000000 | NitroBZ | 1.400000116e-10

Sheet: Tabla original
Datos originales organizados en formato de simulador, sin corrientes NADA
 | Unit | NB Fresh | H2-FRESH | NB-310 | H2-310 | MIX-GAS | GAS-5BAR | GAS-340 | RX-OUT | GAS-250 | GAS-30 | H2-SPLIT | LIQ-SPLIT | ORG-110 | AN-NB FONDO | H2O-NB | AN-NB-110 | H2-ANTORCHA | ORGANICA | H2O-FONDO_1 | ANILINA-NB-SEP | H2O-FONDO_2 | H2-1ATM | H2 TOTAL | REC-H2 | PURGA-ANTORCHA | REC | AN-NB MIXED | NB-HOT | H2-HOT | NBZ-REC | NB-MIX | ANILINA | NBZ | NBZ 1ATM
Comp Mole Frac (Hydrogen) |  | 0.000000000 | 1.000000000 | 2.0477e-32 | 0.992138285 | 0.827215286 | 0.827215286 | 0.827215286 | 0.414613633 | 0.414613633 | 0.414613633 | 0.978549843 | 0.000068845 | 0.000118374 | 1.16818e-29 | 0.000001402 | 1.16818e-29 | 0.094481306 | 0.000118374 | 0.000027881 | 0.000014484 | 0.000001080 | 0.978549843 | 0.992138285 | 0.978549843 | 0.978549843 | 0.978549843 | 0.000000119 | 2.0477e-32 | 0.992138285 | 1.0004e-30 | 2.0477e-32 | 0.000000121 | 1.3079e-143 | 1.3079e-143
Comp Mole Frac (NitroBZ) |  | 1.000000000 | 0.000000000 | 0.999999962 | 0.000011606 | 0.166239520 | 0.166239520 | 0.166239520 | 0.007912305 | 0.007912305 | 0.007912305 | 0.000031665 | 0.013705297 | 0.030214428 | 0.039072547 | 0.004490540 | 0.039072547 | 0.039242571 | 0.030214428 | 0.000050841 | 0.175559676 | 0.000280367 | 0.000031665 | 0.000011606 | 0.000031666 | 0.000031666 | 0.000031666 | 0.040194117 | 0.999999962 | 0.000011606 | 0.999998120 | 0.999999962 | 0.019858978 | 0.999998121 | 0.999998121
Comp Mole Frac (H2O) |  | 0.000000000 | 0.000000000 | 2.0477e-32 | 0.007637290 | 0.006367744 | 0.006367744 | 0.006367744 | 0.387367594 | 0.387367594 | 0.387367594 | 0.020837827 | 0.656800557 | 0.249258028 | 0.001982786 | 0.963346863 | 0.001982786 | 0.816699502 | 0.249258028 | 0.993872929 | 0.134153019 | 0.983754108 | 0.020837827 | 0.007637290 | 0.020837827 | 0.020837827 | 0.020837827 | 0.003068882 | 2.0477e-32 | 0.007637290 | 1.0004e-30 | 2.0477e-32 | 0.003133900 | 9.9969e-31 | 9.9969e-31
Comp Mole Frac (Aniline) |  | 0.000000000 | 0.000000000 | 0.000000038 | 0.000212820 | 0.000177449 | 0.000177449 | 0.000177449 | 0.190106469 | 0.190106469 | 0.190106469 | 0.000580665 | 0.329425300 | 0.720409170 | 0.958944667 | 0.032161194 | 0.958944667 | 0.049576621 | 0.720409170 | 0.006048349 | 0.690272821 | 0.015964445 | 0.000580665 | 0.000212820 | 0.000580665 | 0.000580665 | 0.000580665 | 0.956736882 | 0.000000038 | 0.000212820 | 0.000001880 | 0.000000038 | 0.977007001 | 0.000001879 | 0.000001879

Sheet: Resumen
Resumen de composiciones molares, sin corrientes NADA
Componente | Corriente con mayor fracción | Fracción molar máxima | Componente dominante | Cantidad de corrientes | Porcentaje
Hydrogen | H2-FRESH | 1.000000000 | Hydrogen | 15 | 44.1%
NitroBZ | NB Fresh | 1.000000000 | NitroBZ | 7 | 20.6%
H2O | H2O-FONDO_1 | 0.993872929 | H2O | 5 | 14.7%
Aniline | ANILINA | 0.977007001 | Aniline | 7 | 20.6%
Nota
Se eliminaron las corrientes NADA, NADA-2 y NADA_1.
Los datos se organizaron por corriente en filas y por componente en columnas.
La columna Suma verifica que las fracciones molares de Hydrogen, NitroBZ, H2O y Aniline sumen aproximadamente 1.
La columna Componente dominante indica el componente con mayor fracción molar en cada corriente.

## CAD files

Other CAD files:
PID/DWG/COLUMNAT100.dwg
PID/DWG/COMPRESOR.dwg
PID/DWG/Tanque hidrógeno.dwg
PID/DWG/intercambiador de hidrogeno.dwg
PID/DWG/Intercambiador despues del reactor.dwg
PID/DWG/SEGUNDO ENFRIADOR DEL REACTOR.dwg
PID/DWG/INTERCAMBIADOR NITROBENCENO.dwg
PID/DWG/Torre de destilación T101.dwg
PID/DWG/intercambiador de mezcla caliente.dwg
PID/DWG/Calentador fase organica.dwg
PID/DWG/MIXER102.dwg
PID/DWG/Separador 001.dwg
PID/DWG/Enfriador primera columna.dwg
PID/DWG/Decantador V102.dwg
PID/DWG/BLANKETING.dwg
PID/DWG/ANTORCHA.dwg
PID/DWG/tanque de nitrobenceno.dwg
PID/DWG/reactor enchaquetado.dwg
PID/DWG/Calentador_fase_organica.dwg
PID/DWG/Decantador V100.dwg

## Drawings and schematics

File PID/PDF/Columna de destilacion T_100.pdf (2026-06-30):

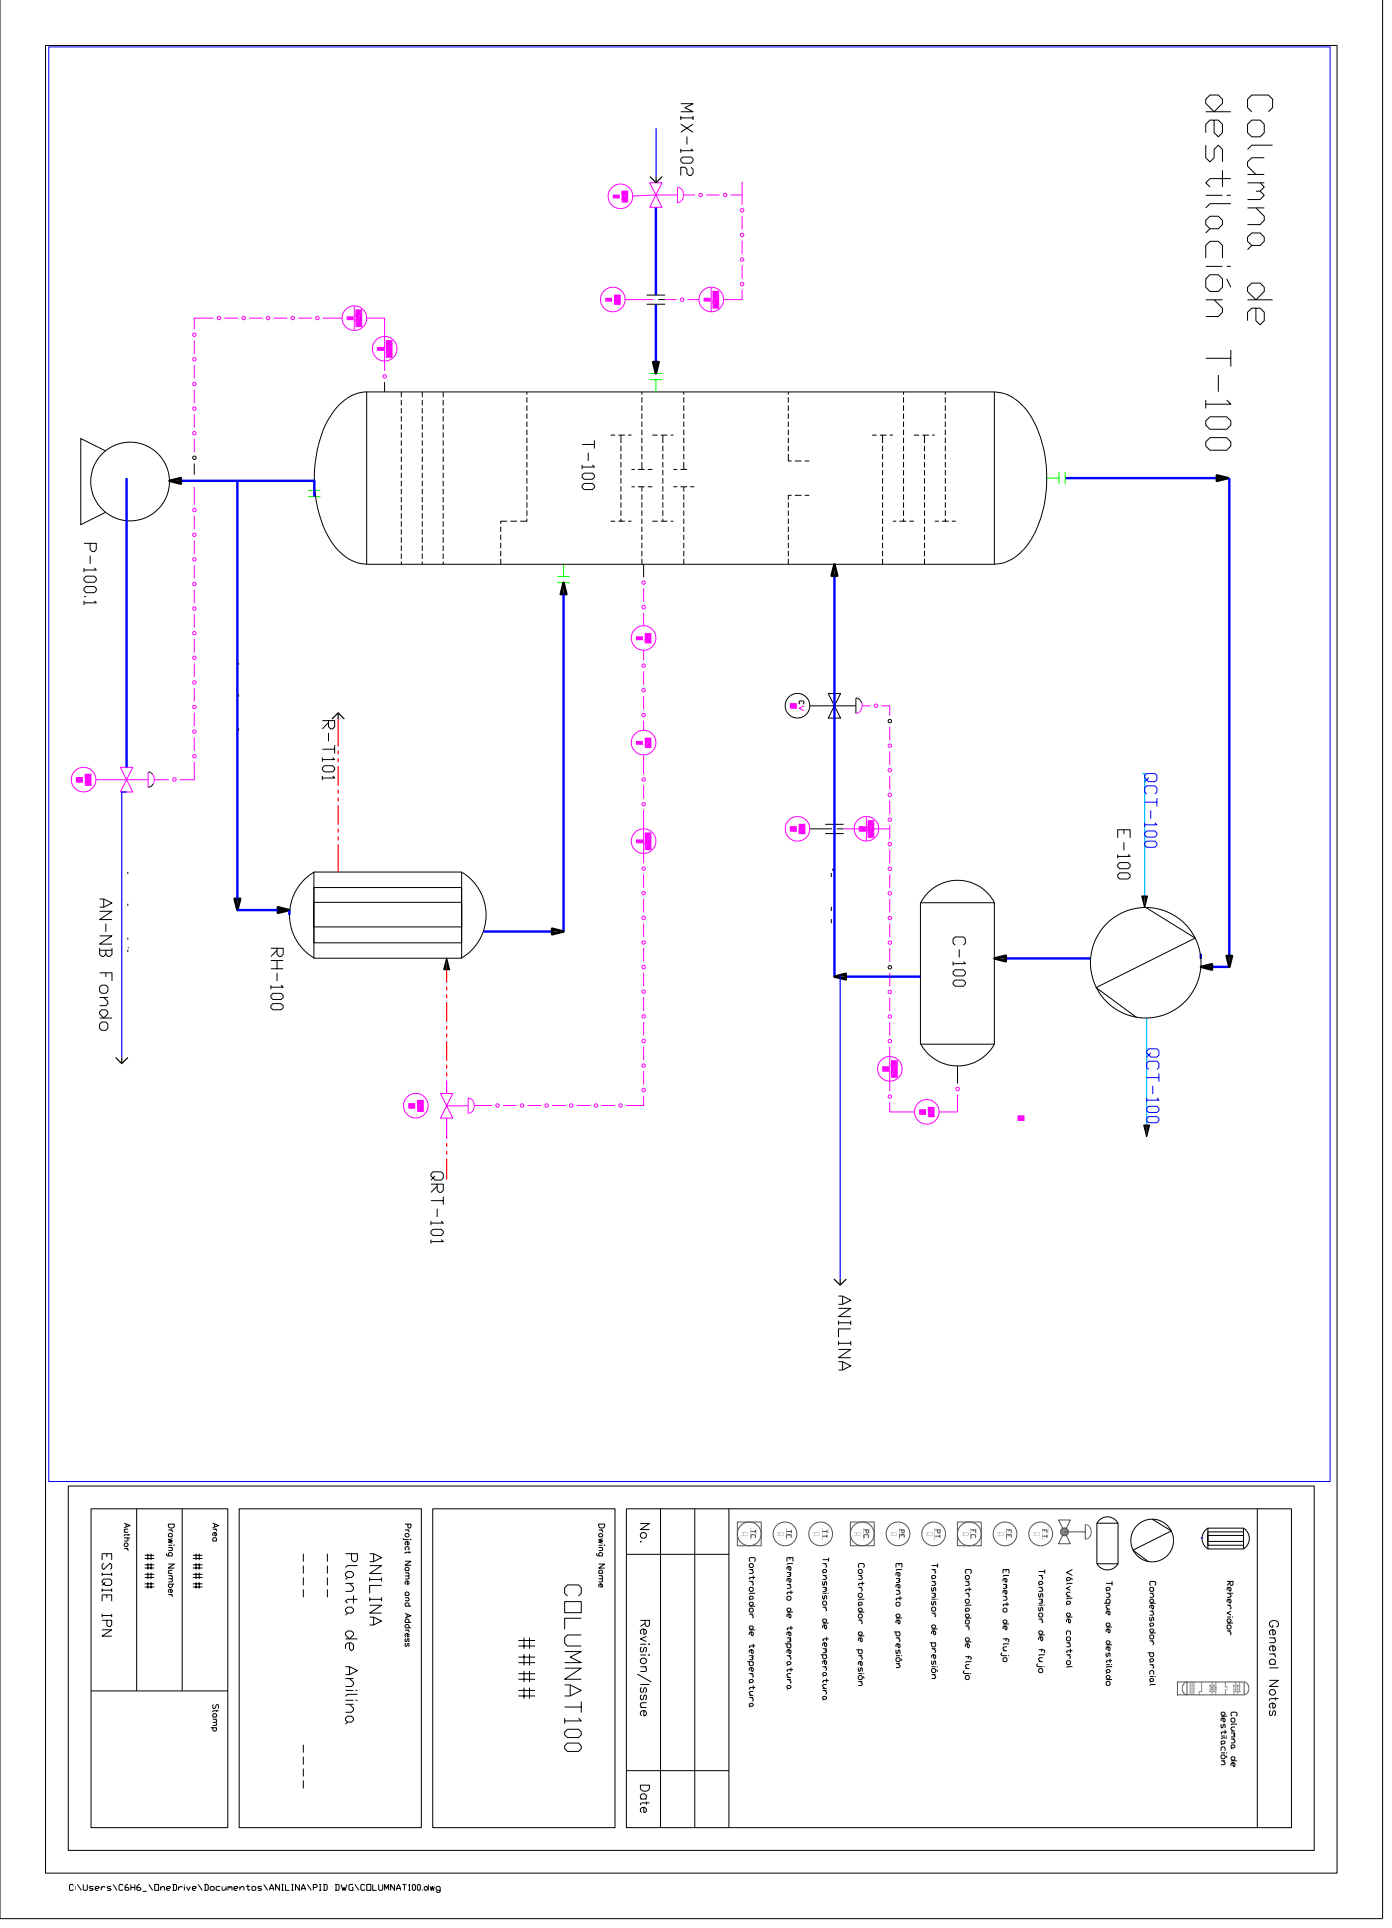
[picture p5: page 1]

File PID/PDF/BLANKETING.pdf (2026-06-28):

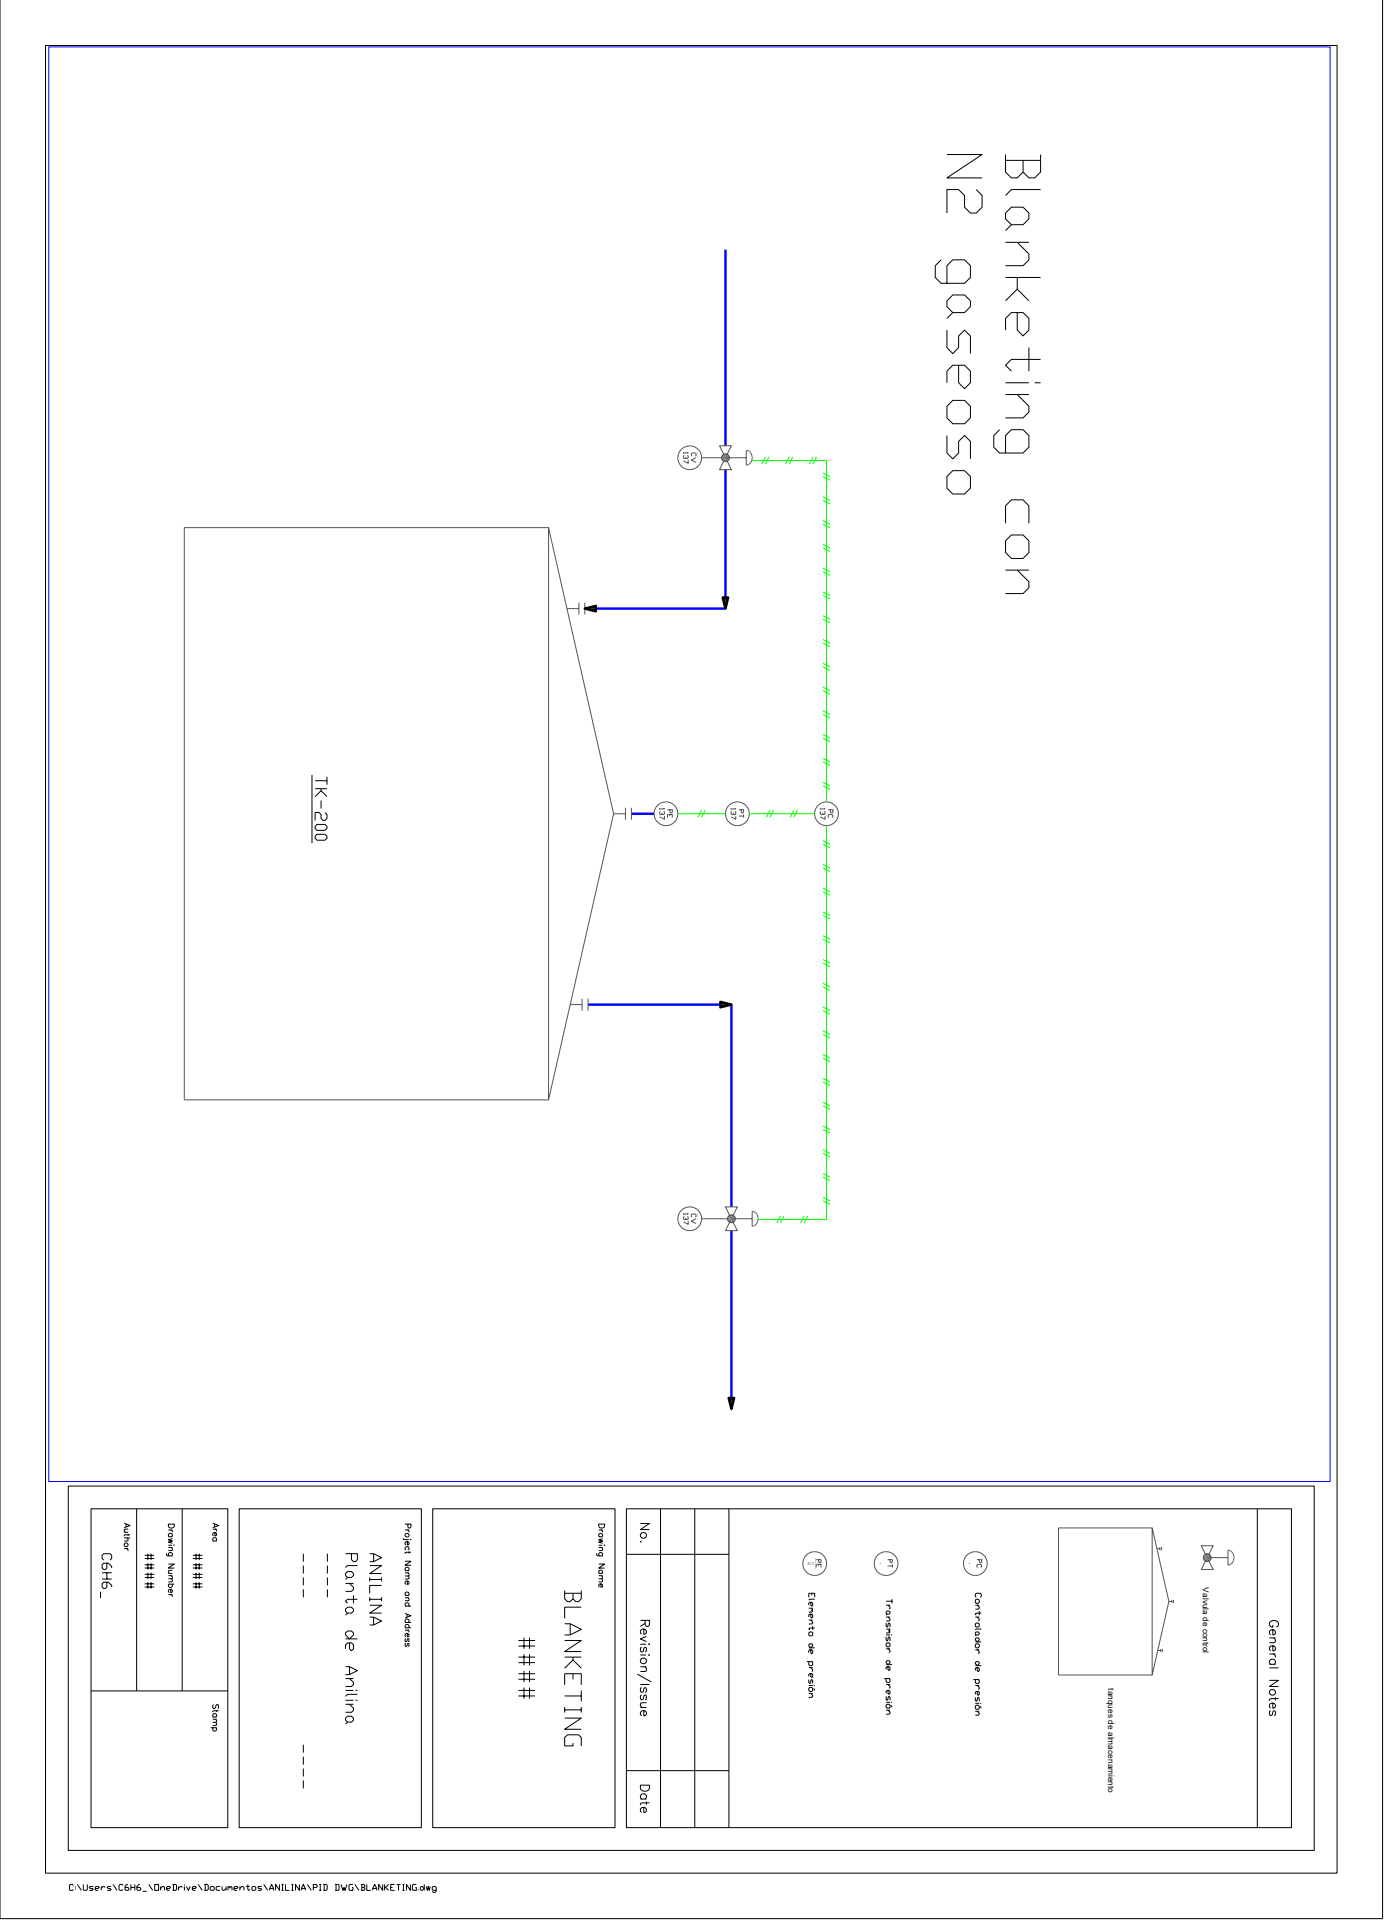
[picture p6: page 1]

tanques de almacenamiento Valvula de control

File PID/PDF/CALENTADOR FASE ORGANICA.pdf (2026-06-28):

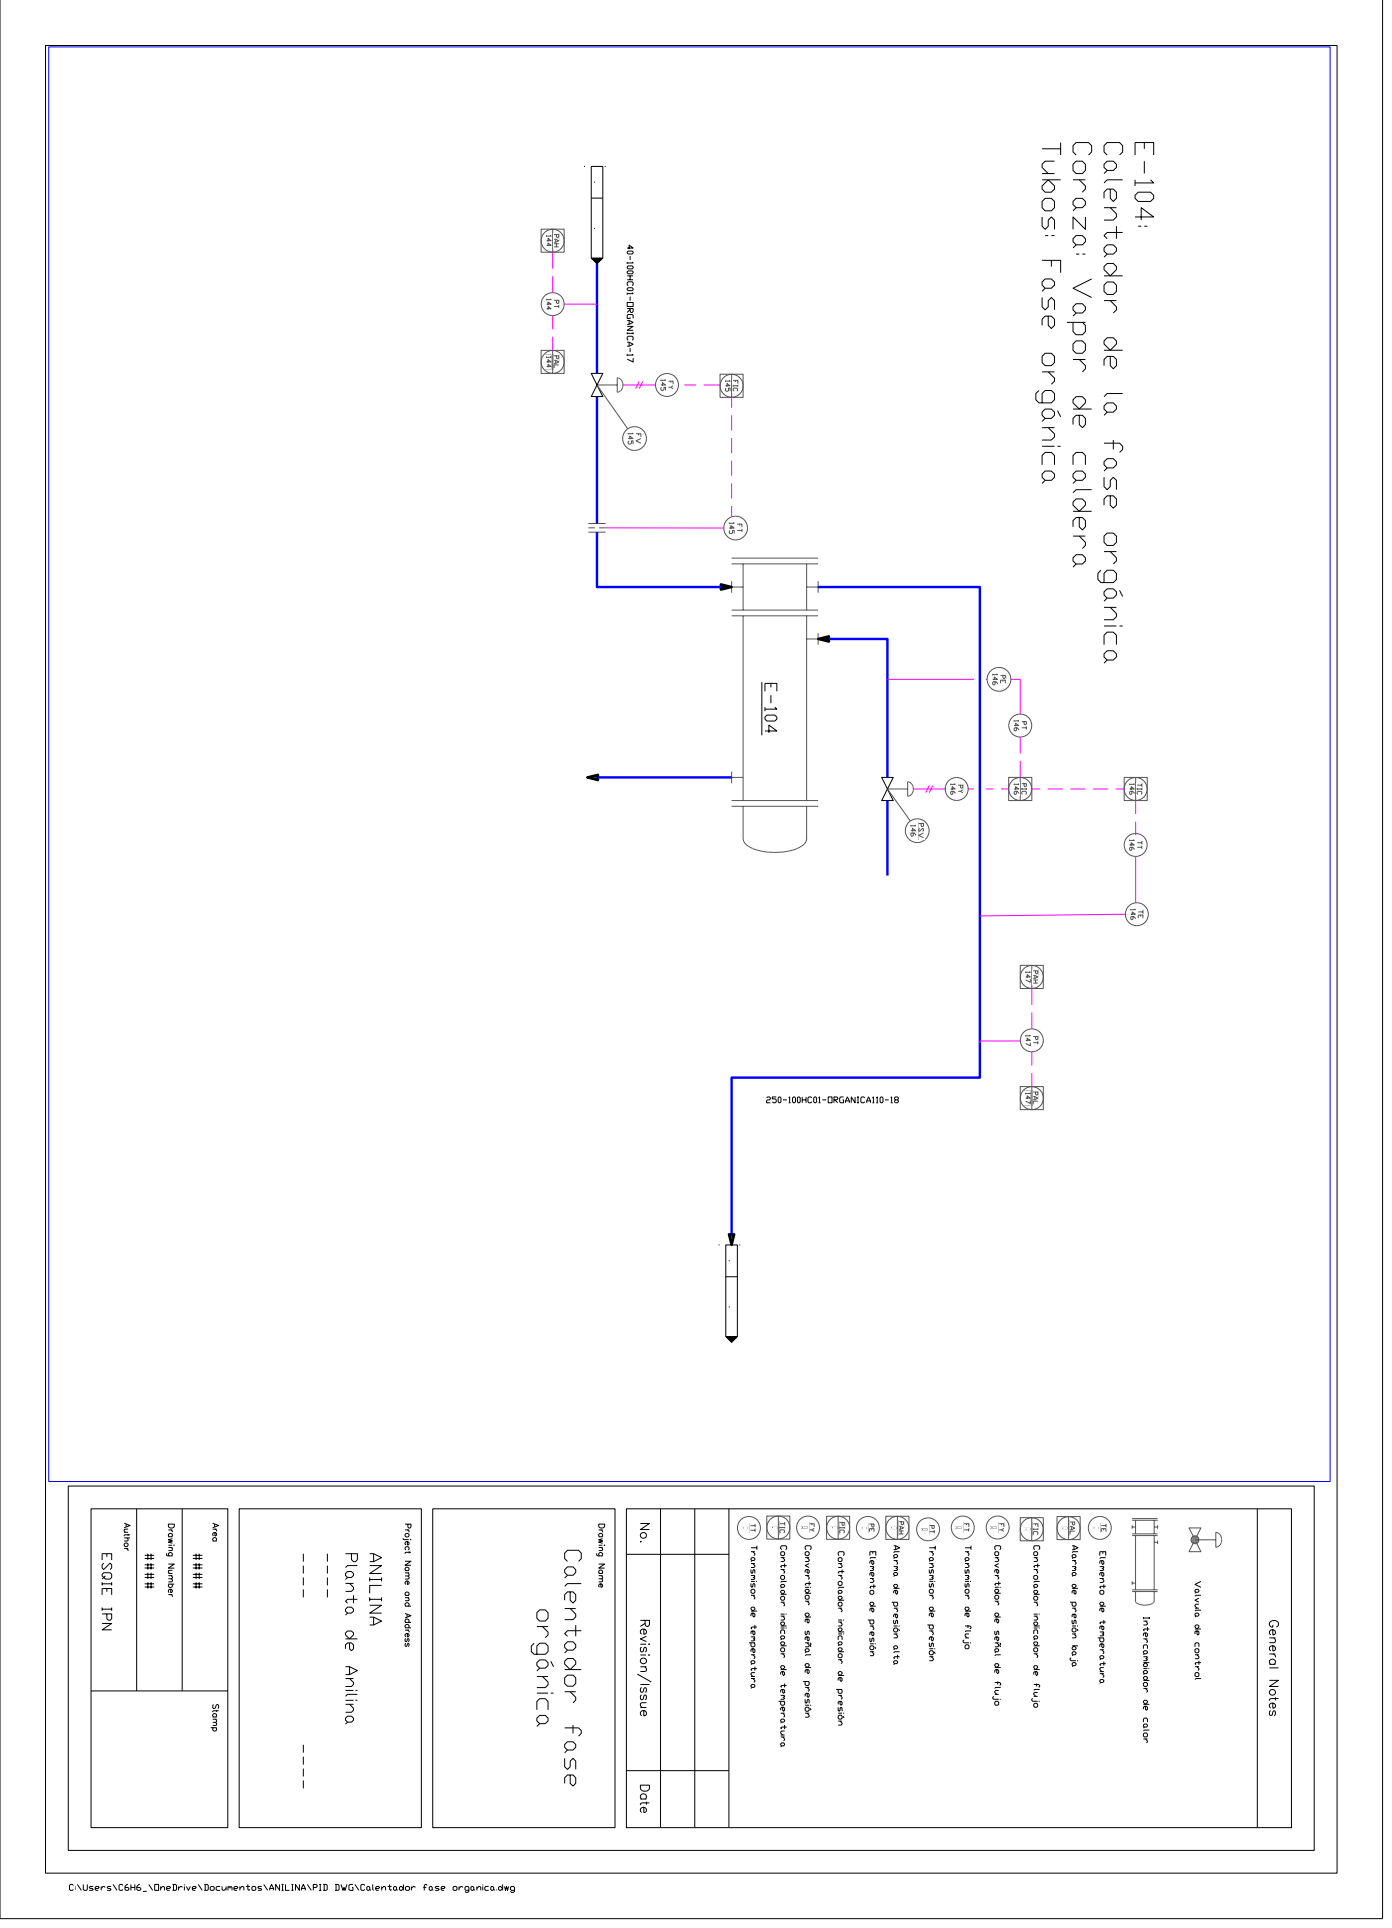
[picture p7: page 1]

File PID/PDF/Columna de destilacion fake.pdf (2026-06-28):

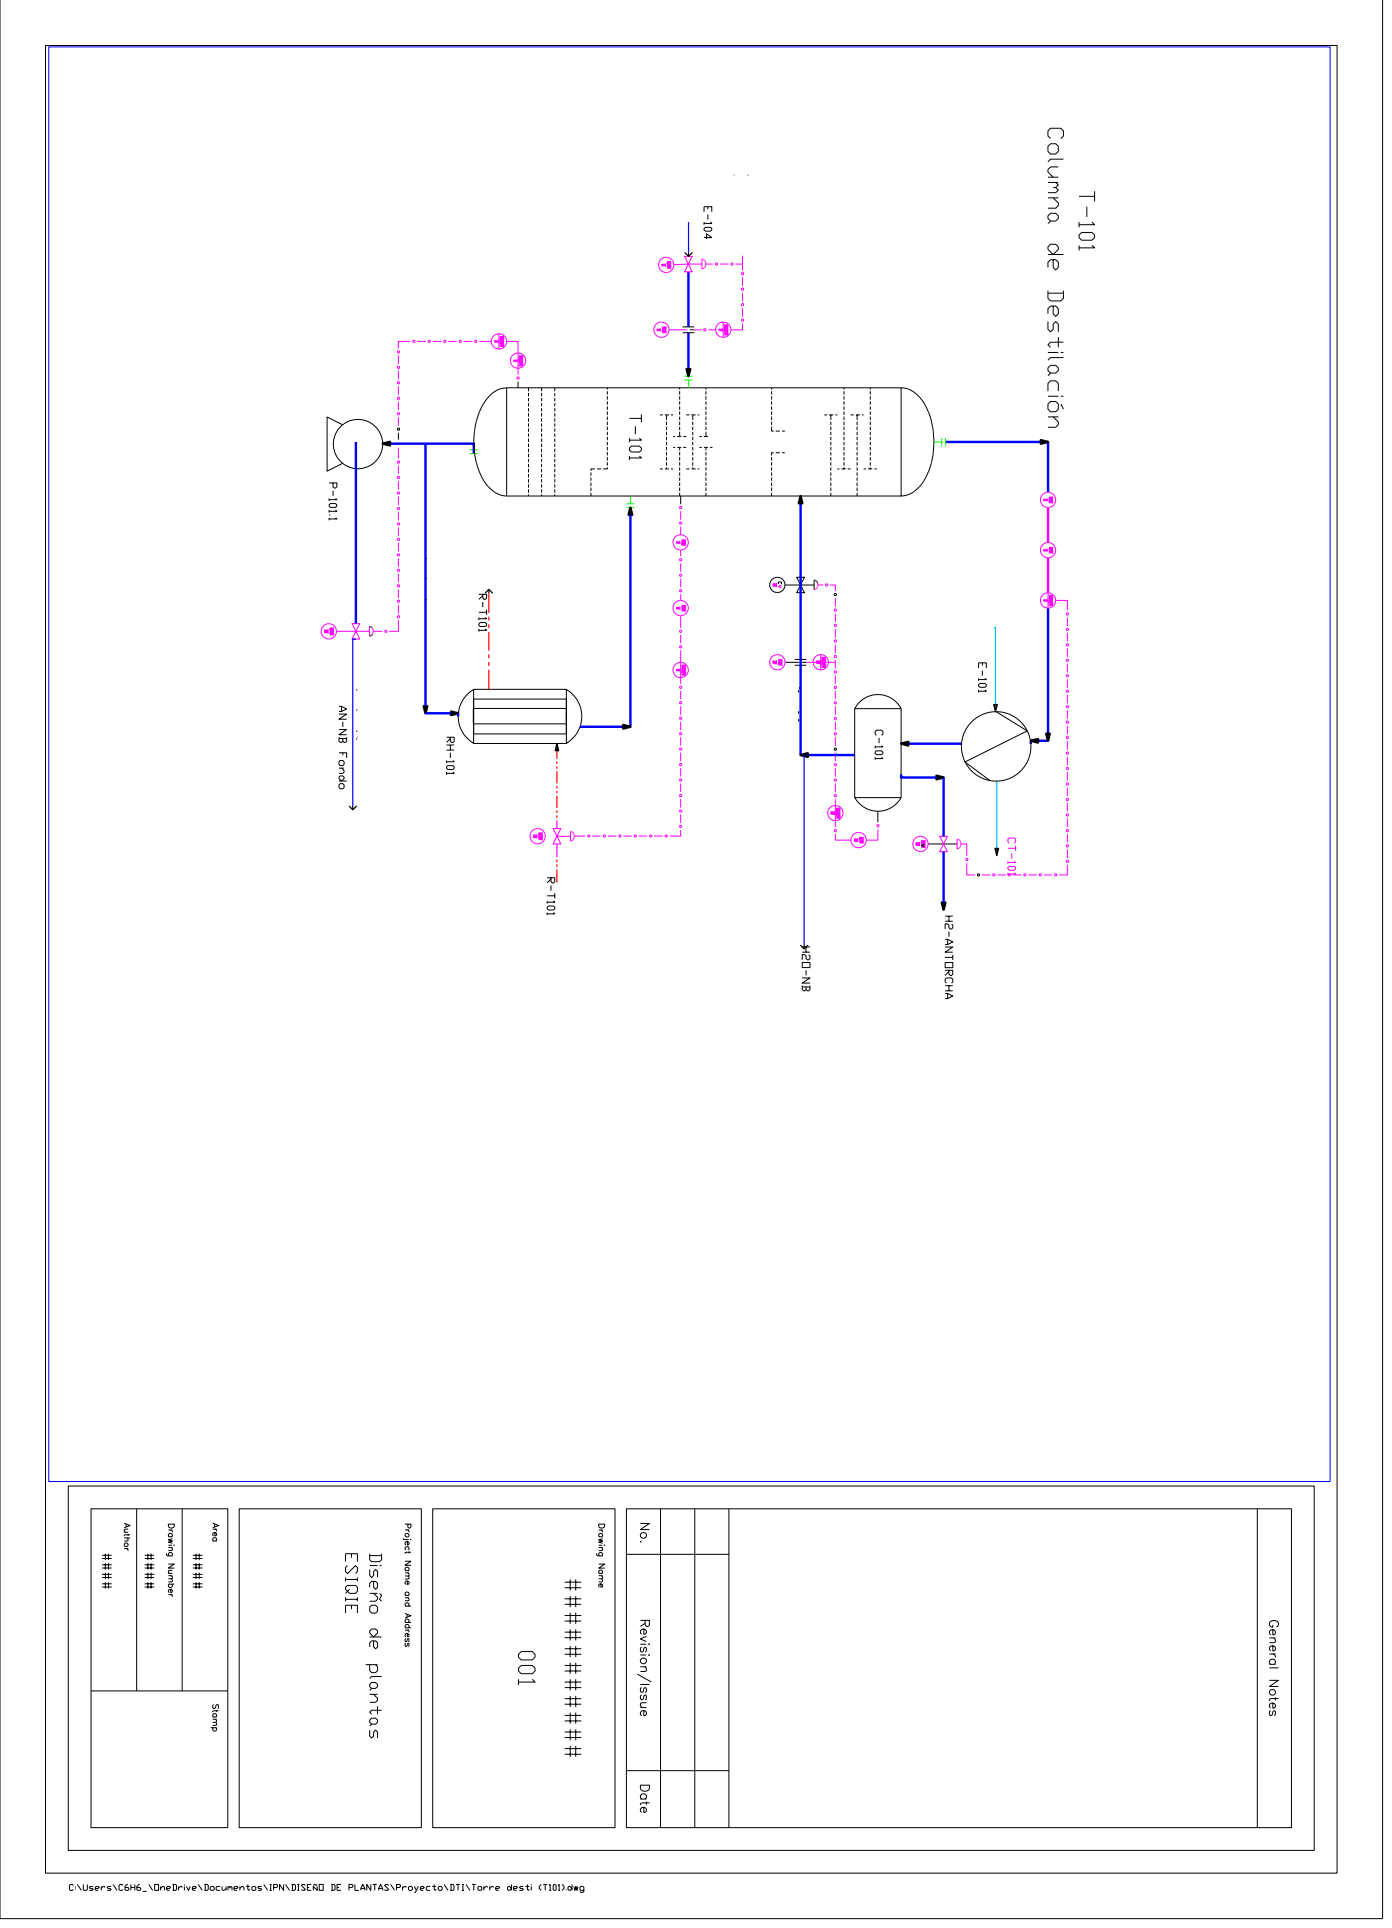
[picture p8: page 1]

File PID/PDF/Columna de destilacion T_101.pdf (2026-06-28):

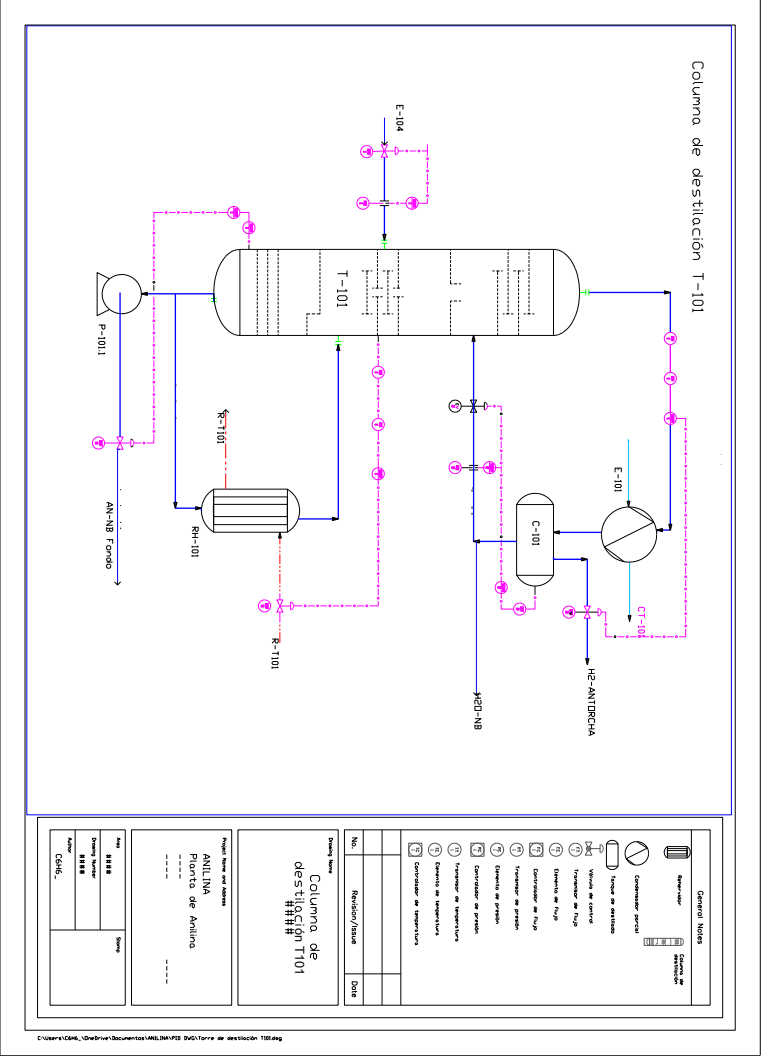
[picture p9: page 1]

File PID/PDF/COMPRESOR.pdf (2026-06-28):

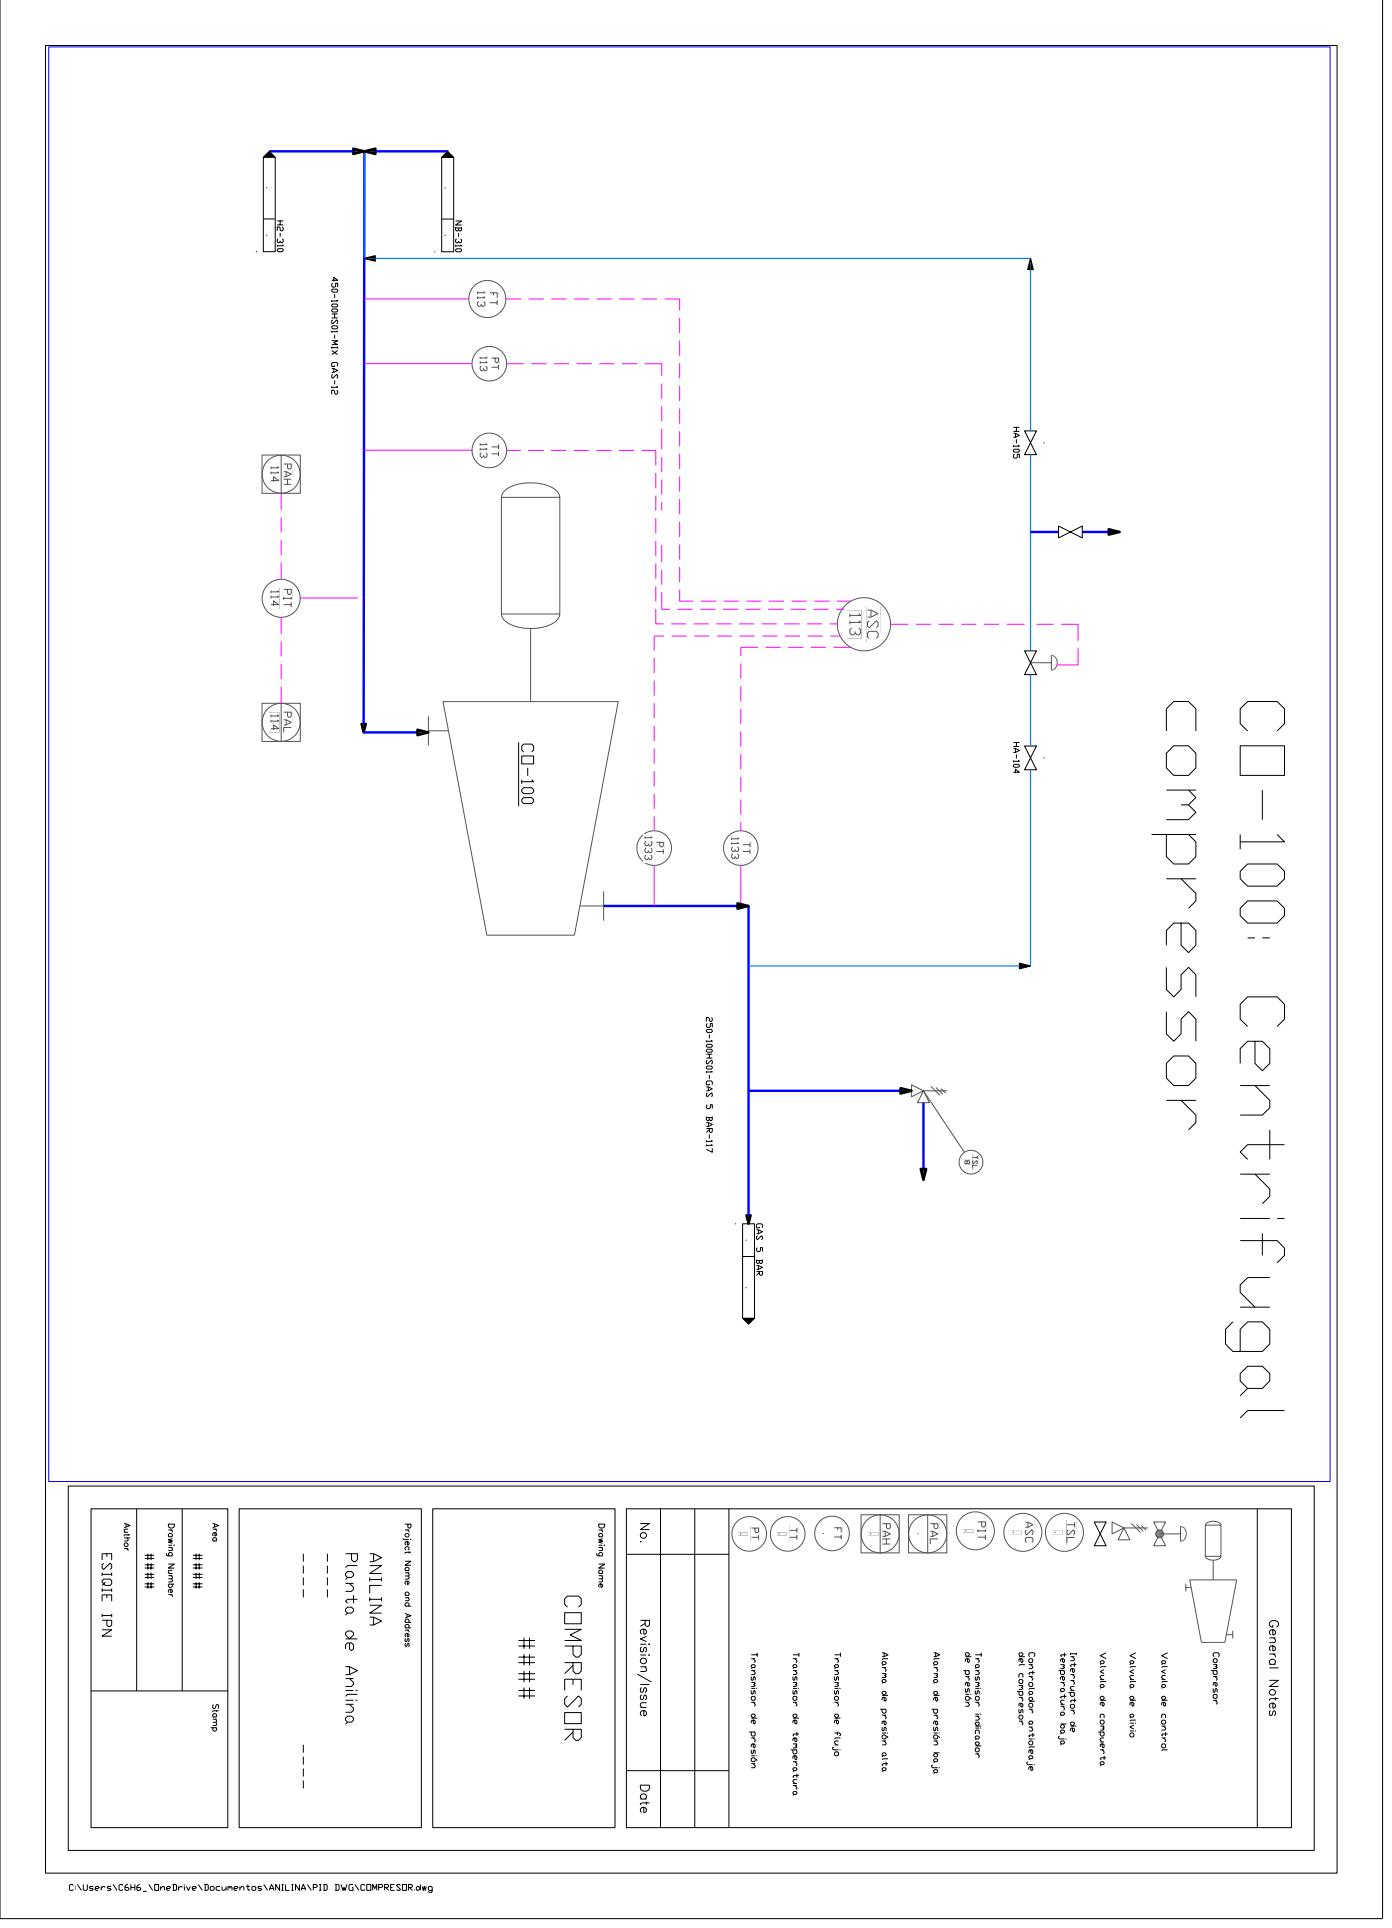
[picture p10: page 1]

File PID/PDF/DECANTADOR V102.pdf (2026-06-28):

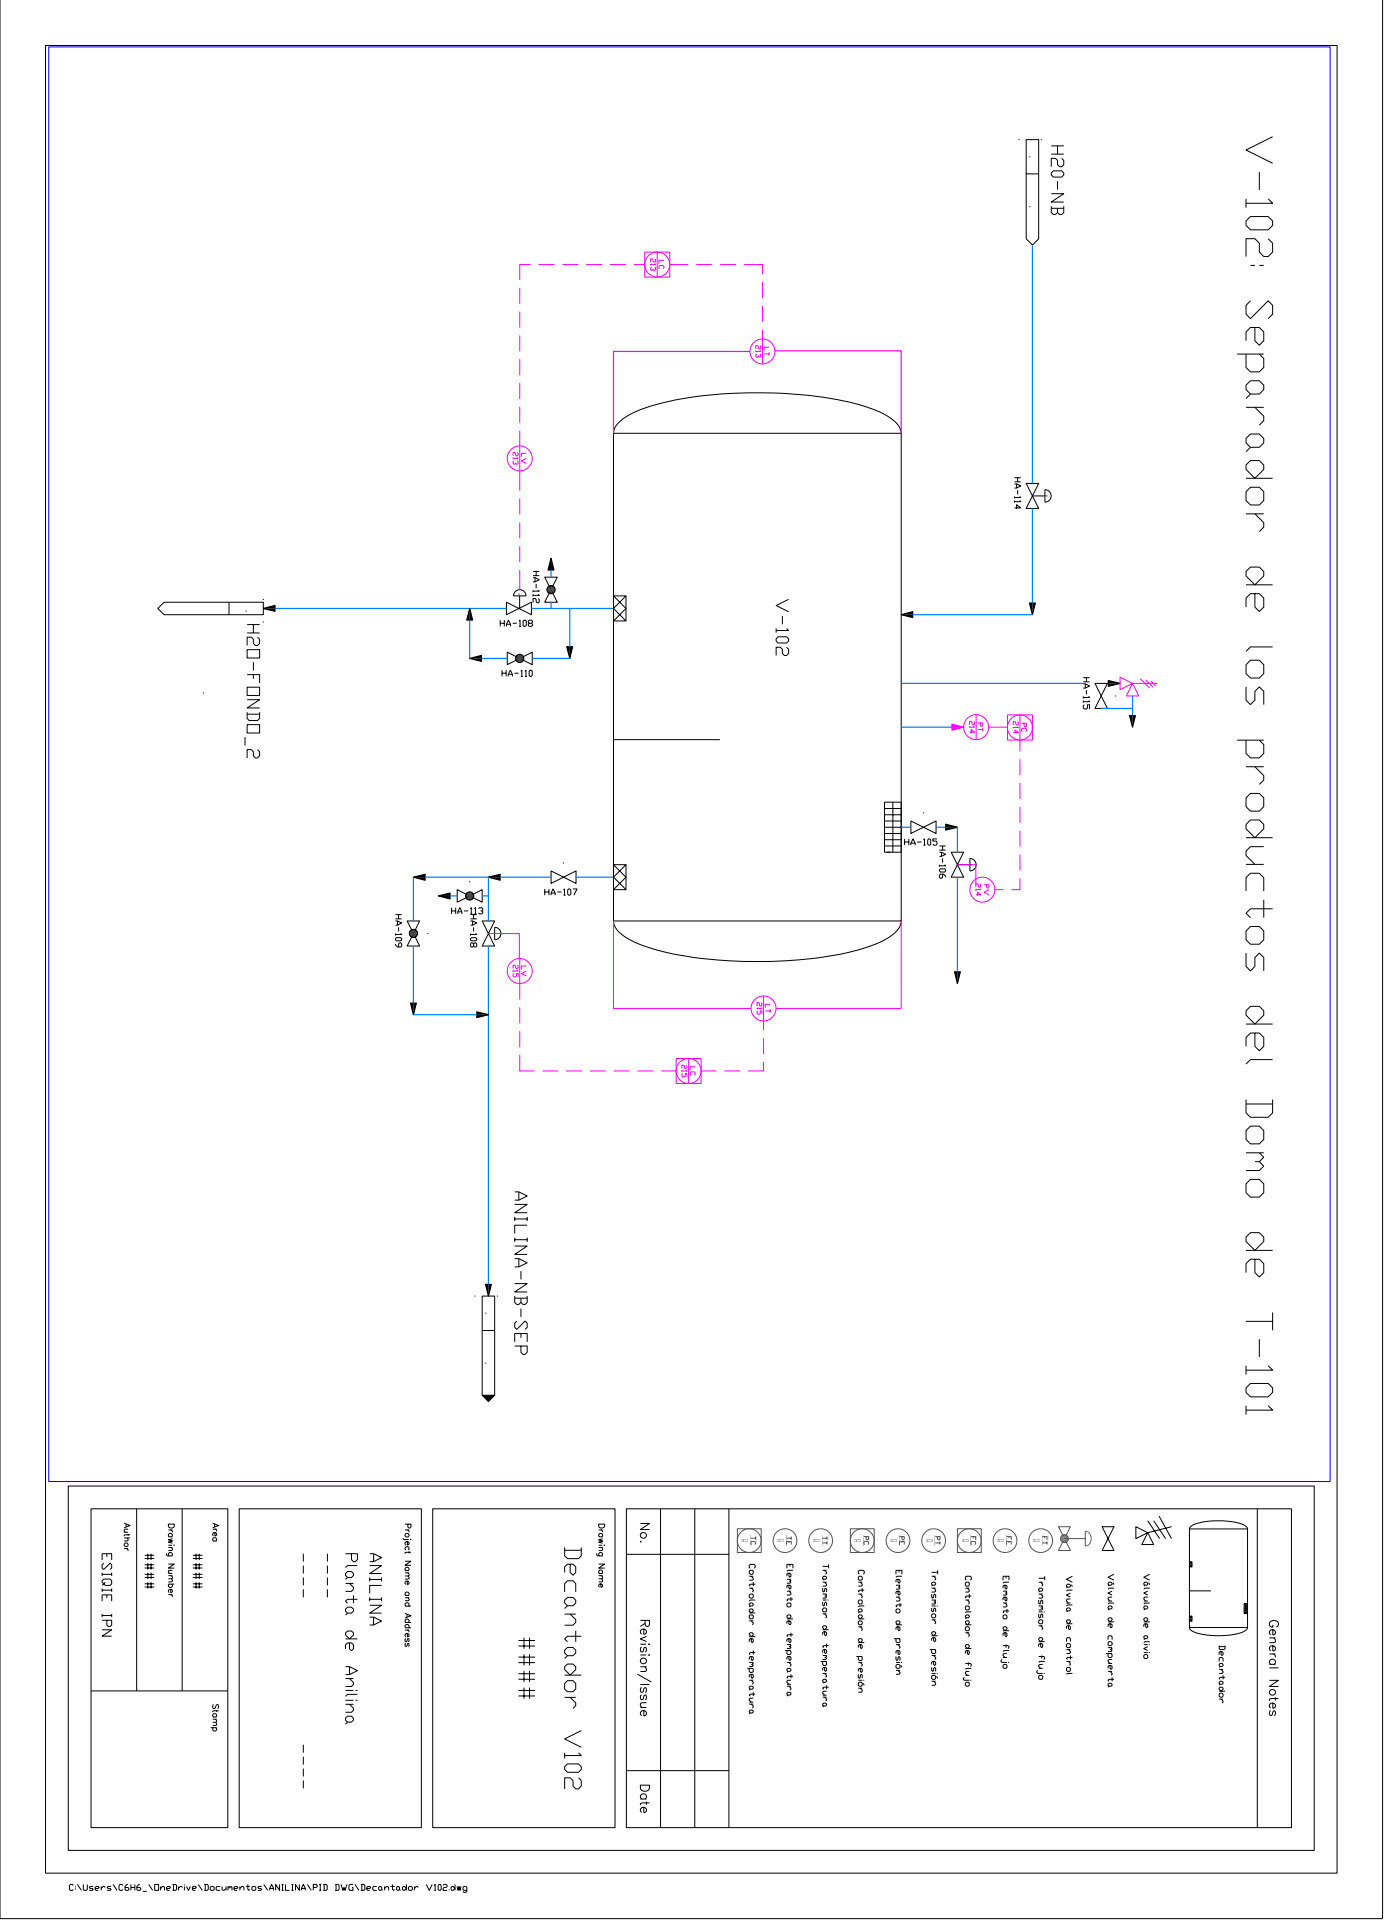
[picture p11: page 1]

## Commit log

2026-06-28 PROYECTO ACABADO
    [ANTORCHA.dwg, BLANKETING.dwg, COLUMNAT100.dwg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]
2026-06-30 correcciones actualizadas
    [COLUMNAT100.dwg]
2026-06-30 Modificaciones de archivos no necesarios
